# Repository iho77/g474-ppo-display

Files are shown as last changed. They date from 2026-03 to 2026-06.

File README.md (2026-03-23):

Shield: [][cc-by-nc]

This work is licensed under a
[Creative Commons Attribution-NonCommercial 4.0 International License][cc-by-nc].

[][cc-by-nc]

[cc-by-nc]: https://creativecommons.org/licenses/by-nc/4.0/
[cc-by-nc-image]: https://licensebuttons.net/l/by-nc/4.0/88x31.png
[cc-by-nc-shield]: https://img.shields.io/badge/License-CC%20BY--NC%204.0-lightgrey.svg

---

## DISCLAIMER — IMPORTANT, READ BEFORE USE

**THIS DEVICE IS A HOBBYIST PROTOTYPE AND EXPERIMENTAL RESEARCH TOOL. IT IS NOT A CERTIFIED DIVING INSTRUMENT, MEDICAL DEVICE, OR SAFETY EQUIPMENT OF ANY KIND.**

This firmware and associated hardware design are provided strictly for educational, experimental, and non-commercial purposes. The device has not been tested, validated, or certified to any safety standard (including but not limited to EN 13949, CE, FCC, or any diving equipment directive). Sensor readings, alarm thresholds, and all computed values may be inaccurate, delayed, or absent without warning.

**DO NOT use this device as a primary or backup oxygen monitoring system in any diving, life support, hyperbaric, medical, or other safety-critical application.** Reliance on this device in any situation involving risk to life or health is done entirely at the user's own risk.

TO THE MAXIMUM EXTENT PERMITTED BY APPLICABLE LAW, THE AUTHORS AND CONTRIBUTORS DISCLAIM ALL WARRANTIES, EXPRESS OR IMPLIED, INCLUDING BUT NOT LIMITED TO WARRANTIES OF MERCHANTABILITY, FITNESS FOR A PARTICULAR PURPOSE, AND NON-INFRINGEMENT. IN NO EVENT SHALL THE AUTHORS BE LIABLE FOR ANY DIRECT, INDIRECT, INCIDENTAL, SPECIAL, EXEMPLARY, OR CONSEQUENTIAL DAMAGES (INCLUDING DEATH, PERSONAL INJURY, OR PROPERTY DAMAGE) ARISING FROM THE USE OF OR INABILITY TO USE THIS DEVICE OR FIRMWARE, EVEN IF ADVISED OF THE POSSIBILITY OF SUCH DAMAGE.

**Use of this project implies full acceptance of these terms.**

---

# STM32G474 PPO Display Firmware

Firmware for a DIY PPO2 (Partial Pressure of Oxygen) display unit based on the **STM32G474CC** microcontroller. Designed for rebreather divers who want to build and understand their own monitoring electronics.

## Features

### PPO2 Monitoring
- Reads up to three galvanic oxygen cells simultaneously via dedicated ADC channels with OPAMPs
- Displays PPO2 in bar (e.g., 1.30) for each sensor on a colour TFT screen
- Two configurable setpoints (SP1 / SP2) with quick in-dive switching via button

### Warning System
- **DRIFT** (yellow): sensor has deviated more than the configured threshold from the active setpoint
- **NEAR LIMIT** (red border): PPO2 is approaching the configured minimum or maximum safe limit
- **CRITICAL** (red background): PPO2 has crossed the minimum or maximum limit — immediate action required
- Warnings are shown per-sensor with colour-coded borders, panel backgrounds, and text
- Haptic alerts via vibration motor with distinct patterns per severity:
  - Drift → one short pulse per second
  - Near limit → two medium pulses per second
  - Critical → three rapid pulses per second
- Press the menu button to silence the vibration while the visual warning remains on screen; the vibration will resume only if the warning level changes

### Sensor Drift Tracking
- Continuously monitors the rate of change of each sensor's PPO2 over a 3-minute window
- Drift rate (mbar/min) is displayed in real time to catch failing or degrading cells early

### Depth and Temperature
- Pressure sensor (MS5837) measures ambient pressure for depth calculation
- Depth displayed in metres; temperature available in raw sensor data screen

### Two-Point Sensor Calibration
- Calibrate any sensor against two known PPO2 reference points
- Calibration coefficients stored persistently in external SPI flash
- Sensor diagnostic screen shows sensitivity history to identify cell degradation over time

### Settings
- Configurable thresholds: minimum PPO, maximum PPO, warning distance, sensor divergence limit
- Two independent setpoints with configurable values
- Display brightness control with gamma correction
- All settings survive power cycles via wear-levelled external flash storage

### Dive Log
- Session data viewable on device

### Power Management
- Battery voltage and percentage displayed at all times
- Low battery warning
- Auto power-off after configurable idle period

---

## Hardware

- MCU: STM32G474CCTx (Cortex-M4, 170 MHz, 256 KB Flash, 128 KB RAM)
- Display: SPI TFT driven via DMA
- Pressure sensor: MS5837 via I2C
- External SPI flash for calibration/log storage (W25Q128)
- Vibration motor on PA0 (TIM5 CH1 PWM)
- Custom PCB (schematics in `Schematics/`)
- Enclosure model in `Housing/`

---

## Software Architecture

```
┌─────────────────────────────────────────────────────────────┐
│                        Application                          │
│                                                             │
│  screen_manager ──► screen_main / screen_settings /        │
│                      screen_calibration / screen_menu / … │
│       │                         │                           │
│  button (EXTI)            warning ◄──── sensor              │
│                             │               │               │
│                          vibro FSM      drift_tracker       │
│                         (TIM5 PWM)    (linear regression)   │
│                                           │                 │
│  settings_storage ◄──► ext_flash_storage  │                 │
│  (wear-levelled W25Q128 via SPI DMA)      │                 │
│                                           │                 │
│  pressure_sensor ◄──── ms5837 (I2C IT)   │                 │
│                                           │                 │
│  sensor_diagnostics ◄─────────────────────┘                 │
└─────────────────────────────────────────────────────────────┘
┌─────────────────────────────────────────────────────────────┐
│                    HAL / CubeMX Layer                       │
│  TIM6 1kHz scheduler │ ADC1-4 DMA │ SPI1/2 DMA │ I2C1 IT  │
│  TIM2 backlight PWM  │ TIM5 vibro │ EXTI buttons           │
└─────────────────────────────────────────────────────────────┘
```

### Major Modules

| Module | File(s) | Responsibility |
|---|---|---|
| Screen manager | `screen_manager.c/.h` | Screen lifecycle (create → load → delete), button routing |
| Warning | `warning.c/.h` | PPO2 threshold checks, visual styles, vibro state machine |
| Sensor | `sensor.c/.h` | ADC → microvolts → PPO2 conversion, validity tracking |
| Drift tracker | `drift_tracker.c/.h` | 3-minute linear regression on PPO2 samples (10 s interval) |
| Sensor diagnostics | `sensor_diagnostics.c/.h` | Calibration history analysis, sensitivity degradation detection |
| Pressure sensor | `pressure_sensor.c/.h` + `ms5837.c/.h` | Depth/temperature from MS5837 via I2C interrupt-driven FSM |
| Settings storage | `settings_storage.c/.h` | Read/write 7 user parameters to external flash |
| External flash | `ext_flash_storage.c/.h` + `w25q128.c/.h` | Wear-levelled page storage on W25Q128 SPI NOR flash |
| Button | `button.c/.h` | EXTI debounce, event queue for BTN_M / BTN_S |
| Display driver | `st7789v.c/.h` | SPI DMA flush, LVGL integration |

### Scheduler

A 1 kHz hardware timer (TIM6) drives four software tick rates:

| Rate | Handler | Work done |
|---|---|---|
| 5 ms | `g_flag_5ms` | LVGL render, vibro motor FSM tick |
| 20 ms | `g_flag_20ms` | Button event dispatch |
| 1 Hz | `g_flag_1hz` | Screen update, PPO2 warnings, battery check |
| 10 s | `g_flag_10s` | Drift tracker sample (3 sensors) |

---

## Repository Layout

```
Core/                          # CubeMX-generated core (Inc/, Src/)
STM32CubeIDE/
  Application/User/Core/       # Application source code
  Drivers/
    lvgl/                      # LVGL v8.3.11 (git submodule)
    lv_conf.h                  # LVGL configuration
  STM32G474CCTX_FLASH.ld       # Linker script (256 KB single-bank)
Drivers/                       # ST HAL / CMSIS (excluded from repo)
Schematics/                    # EasyEDA schematic exports
Housing/                       # FreeCAD enclosure model
stm32g474_PPO_Display.ioc      # STM32CubeMX project
```

> `Drivers/` (CMSIS + STM32G4xx HAL) is excluded — regenerate via STM32CubeMX.

---

## Safety Audit

A static safety audit of all application firmware was conducted on 2026-03-23, covering fault handling, ISR/main-loop data races, arithmetic overflow, sensor validity propagation, and stack usage.

- 15 findings identified (4 HIGH, 7 MEDIUM, 5 LOW / CRITICAL: 0)
- All actionable findings resolved in the same session
- Full report, per-finding evidence, and resolution details: [`.pipeline/safety_audit.md`](.pipeline/safety_audit.md)

---

## Building

Requires **STM32CubeIDE 1.19+**.

1. Clone with submodules:
   ```bash
   git clone --recurse-submodules https://github.com/iho77/g474-ppo-display.git
   ```
2. Open the workspace in STM32CubeIDE (`STM32CubeIDE/` folder).
3. Run **Project → Build All** (first build regenerates `subdir.mk` and `objects.list`).
4. After the first IDE build, command-line builds also work:
   ```bash
   cd STM32CubeIDE/Debug
   make -j4 all
   arm-none-eabi-size stm32g474_PPO_Display.elf
   ```

### Restoring excluded drivers

If you cloned fresh and `Drivers/` is empty, open the `.ioc` in STM32CubeMX and click **Generate Code** to restore CMSIS and HAL sources.

## Flash Memory Note

The G474CC ships with **DBANK=1** (dual 128 KB banks). The linker script uses a single 256 KB bank layout — ensure Option Bytes are set to `DBANK=0` before flashing.

---

## License

Application code: MIT.
LVGL: MIT (see `STM32CubeIDE/Drivers/lvgl/LICENCE.txt`).
ST HAL / CMSIS: BSD-3 / Apache-2.0 (see respective `LICENSE.txt` files).

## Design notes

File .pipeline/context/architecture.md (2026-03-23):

# Firmware Architecture

## Execution Model
Bare-metal super-loop. TIM6 fires at 1 kHz and sets scheduler flags; the main loop
polls those flags and dispatches periodic work. No RTOS.

## System Clock
PLL from 16 MHz HSI -> 96 MHz system clock (PLLN=12, PLLM=1, PLLR=2).
APB1/APB2 undivided (96 MHz). Flash latency 3 cycles.

## Module Map

| Module | File(s) | Purpose | ISR? | DMA? | Shared state? | External input? |
|---|---|---|---|---|---|---|
| Init & super-loop | Core/Src/main.c | Peripheral init (CubeMX), flag dispatch, HAL callbacks | No | Yes (ADC1-4, SPI2) | Yes | No |
| Interrupt vectors | Core/Src/stm32g4xx_it.c | EXTI, DMA, ADC, I2C, SPI, TIM ISR stubs | Yes | No | Yes | Yes |
| HAL low-level init | Core/Src/stm32g4xx_hal_msp.c | GPIO, DMA, clock MSP hooks | No | No | No | No |
| sensor.c | Application/User/Core/ | ADC->PPO2: Hampel spike filter + dual-EMA, VREFINT ratio calibration, battery voltage | No | Consumes DMA bufs | Yes | Yes (ADC1-4 DMA) |
| pressure_sensor.c | Application/User/Core/ | Depth calculation from MS5837 raw ADC, salt/fresh water selection | No | No | Yes | Yes (I2C1 IT) |
| ms5837.c | Application/User/Core/ | MS5837-30BA I2C driver -- IT-driven FSM (RESET->PROM->D2->D1->READ) | Yes (I2C1 callbacks) | No | Yes | Yes (I2C1) |
| drift_tracker.c | Application/User/Core/ | 3-minute linear regression on PPO2 (10 s samples, circular buffer) | No | No | Yes | No |
| warning.c | Application/User/Core/ | Threshold checks (CRITICAL/NEAR_CRITICAL/DRIFT), vibro motor 3-level PWM FSM | No | No | Yes | No |
| calibration.c | Application/User/Core/ | Two-point sensor calibration workflow | No | No | Yes | No |
| sensor_diagnostics.c | Application/User/Core/ | Calibration history analysis, sensitivity degradation detection | No | No | Yes | No |
| settings_storage.c | Application/User/Core/ | 7-parameter settings: brightness, thresholds, setpoints. Delegates to ext_flash_storage | No | No | Yes | No |
| ext_flash_storage.c | Application/User/Core/ | W25Q128 wear-levelled settings (ping-pong) + append-only calibration log; CRC32 validation | No | No | No | No |
| w25q128.c | Application/User/Core/ | Low-level W25Q128 SPI1 driver (read/write/erase) | No | No | No | No |
| st7789v.c | Application/User/Core/ | ST7789V SPI2 DMA display driver, 20-line partial framebuffer flush | No | Yes (SPI2 DMA1 Ch1) | Yes | No |
| screen_manager.c | Application/User/Core/ | Screen lifecycle: create -> load -> delete; factory pattern | No | No | Yes | No |
| button.c | Application/User/Core/ | EXTI debounce (50 ms), press/hold detection, event queue | Yes (EXTI callback) | No | Yes | Yes (PA2, PA3) |
| screens/screen_main.c | Application/User/Core/screens/ | Primary dive display: 3x PPO2, depth, battery, drift, setpoint selector | No | No | Yes (reads sensor) | No |
| screens/screen_calibration.c | Application/User/Core/screens/ | Two-point calibration UI workflow | No | No | Yes | No |
| screens/screen_settings.c | Application/User/Core/screens/ | User preference editor | No | No | Yes | No |
| screens/screen_menu.c | Application/User/Core/screens/ | Menu navigation hub | No | No | No | No |
| screens/screen_sensor_data.c | Application/User/Core/screens/ | Raw readings, diagnostics view | No | No | Yes | No |
| screens/screen_dive_log.c | Application/User/Core/screens/ | Historical calibration/dive data viewer | No | No | No | No |
| screens/screen_startup.c | Application/User/Core/screens/ | Boot splash, sensor stabilization wait | No | No | No | No |
| screens/screen_power_off.c | Application/User/Core/screens/ | Shutdown confirmation sequence | No | No | No | No |

## Interrupt Handlers

| ISR | Source | Priority | Notes |
|-----|---|---|---|
| SysTick_Handler | 1 ms tick | (HAL default) | Increments LVGL tick; calls button_tick() |
| TIM6_DAC_IRQHandler | TIM6 1 kHz | -- | Sets scheduler flags: g_flag_1hz/5ms/20ms/10s |
| EXTI2_IRQHandler | PA2 (BTN_M) | -- | Routes to button_exti_callback() |
| EXTI3_IRQHandler | PA3 (BTN_S) | -- | Routes to button_exti_callback() |
| DMA1_Channel1_IRQHandler | SPI2 TX complete | 0,0 | HAL_SPI_TxCpltCallback() -> lv_disp_flush_ready() |
| DMA1_Channel4_IRQHandler | ADC1 (SENSOR1) | 0,0 | HAL_ADC_ConvCpltCallback() -> sets g_adc1_new |
| DMA1_Channel5_IRQHandler | ADC2 (SENSOR2) | 0,0 | sets g_adc2_new |
| DMA1_Channel6_IRQHandler | ADC3 (SENSOR3) | 0,0 | sets g_adc3_new |
| DMA1_Channel7_IRQHandler | ADC4 (VREFINT+BAT) | 0,0 | sets g_adc4_new |
| ADC1_2_IRQHandler | ADC1/ADC2 shared | -- | HAL managed |
| ADC3_IRQHandler | ADC3 | -- | HAL managed |
| ADC4_IRQHandler | ADC4 | -- | HAL managed |
| I2C1_EV_IRQHandler | I2C1 event | -- | MS5837 FSM TX/RX complete callbacks |
| I2C1_ER_IRQHandler | I2C1 error | -- | MS5837 FSM -> idle |
| SPI2_IRQHandler | SPI2 general | -- | HAL managed |
| NMI_Handler / HardFault_Handler | -- | -- | Infinite loop (debugger attachment) |

## DMA Channels

| DMA Channel | Peripheral | Buffer | Circular? |
|---|---|---|---|
| DMA1 Channel 1 | SPI2 TX (LCD ST7789V) | 20-line partial framebuffer | No (per-flush) |
| DMA1 Channel 4 | ADC1 (SENSOR1 via OPAMP1) | ADC1_VAL[1] uint16_t | Yes |
| DMA1 Channel 5 | ADC2 (SENSOR2 via OPAMP2) | ADC2_VAL[1] uint16_t | Yes |
| DMA1 Channel 6 | ADC3 (SENSOR3 via OPAMP3) | ADC3_VAL[1] uint16_t | Yes |
| DMA1 Channel 7 | ADC4 (VREFINT + BAT PB12) | ADC4_VAL[2] uint16_t | Yes |

## Communication Interfaces

| Interface | Peripheral | Connected To | Notes |
|---|---|---|---|
| SPI1 | W25Q128 ext flash | PA5=SCK, PB4=MISO, PB5=MOSI, PB6=CS | Blocking HAL calls |
| SPI2 | ST7789V LCD | PB13=SCK, PB15=MOSI, PA10=CS, PA11=DC, PA12=RST | DMA TX, non-blocking |
| I2C1 | MS5837-30BA | Standard-mode, IT-driven (no DMA) | FSM: RESET->PROM->D2->D1->READ |
| ADC1 | OPAMP1 output | SENSOR1 galvanic O2 cell | 16x oversampling, continuous+DMA |
| ADC2 | OPAMP2 output | SENSOR2 galvanic O2 cell | 16x oversampling, continuous+DMA |
| ADC3 | OPAMP3 output | SENSOR3 galvanic O2 cell | continuous+DMA |
| ADC4 ch1/ch3 | VREFINT + PB12 | Internal ref + battery divider | Scan 2ch, DMA |
| TIM5 CH1 | Vibro motor | PA0 (PWM) | 200 Hz, duty 50/75/99% per warning level |
| TIM2 CH3 | LCD backlight | PA9 (PWM) | Gamma-corrected brightness |
| TIM6 | Scheduler | (internal) | 1 kHz, master for periodic flags |
| GPIO EXTI2/3 | Buttons | PA2 (BTN_M), PA3 (BTN_S) | 50 ms debounce |

## GPIO Pin Reference

| Signal | Pin | Function |
|---|-----|---|
| VIB_PWM | PA0 | TIM5 CH1 -- vibro motor PWM |
| SENSOR_1 | PA1 | OPAMP1 input (analog) |
| BTN_M | PA2 | Button Main -- EXTI2 |
| BTN_S | PA3 | Button Select -- EXTI3 |
| FL_SCK | PA5 | SPI1 clock (W25Q128) |
| SENSOR_2 | PA7 | OPAMP2 input (analog) |
| TFT_BLK | PA9 | TIM2 CH3 -- LCD backlight PWM |
| TFT_CS | PA10 | LCD chip-select |
| TFT_DC | PA11 | LCD data/command |
| TFT_RST | PA12 | LCD reset |
| FL_MISO | PB4 | SPI1 MISO (W25Q128) |
| FL_MOSI | PB5 | SPI1 MOSI (W25Q128) |
| FL_CS | PB6 | SPI1 CS (W25Q128) |
| SENSOR_3 | PB0 | OPAMP3 input (analog) |
| SENS_BAT | PB12 | ADC4 ch3 -- battery voltage (3x divider) |
| TFT_SCK | PB13 | SPI2 clock (LCD) |
| TFT_MOSI | PB15 | SPI2 MOSI (LCD) |

## Scheduler Flags (TIM6 @ 1 kHz -> HAL_TIM_PeriodElapsedCallback)

| Flag | Period | Used for |
|---|---|---|
| g_flag_5ms | 5 ms | LVGL timer handler, vibro_tick_5ms() |
| g_flag_20ms | 20 ms | Button event dispatch |
| g_flag_1hz | 1 s | Screen update, PPO2 warning check, battery check |
| g_flag_10s | 10 s | Drift tracker sample |

## Shared Variables (ISR <-> main / module <-> module)

| Variable | Type | Writers | Readers | Protection |
|---|---|---|---|---|
| ADC1_VAL / ADC2_VAL / ADC3_VAL | volatile uint16_t[1] | DMA ISR | sensor.c | atomic flag g_adc1/2/3_new |
| ADC4_VAL | volatile uint16_t[2] | DMA ISR | sensor.c | atomic flag g_adc4_new |
| g_adc1_new .. g_adc4_new | volatile bool / atomic | HAL_ADC_ConvCpltCallback | sensor.c | volatile write, single-reader |
| button event queue | ring buffer | EXTI ISR (button.c) | main loop | volatile head/tail indices |
| sensor_data struct | struct | sensor.c | warning.c, screens | single-writer, read in main loop |
| alarm state | enum | warning.c | screens, vibro FSM | single-writer |
| screen handle | lv_obj_t* | screen_manager.c | screens | single-writer |
| settings struct | struct | settings_storage.c | multiple modules | loaded once at boot, written on save |
| MS5837 FSM state | enum | I2C callbacks (ms5837.c) | pressure_sensor.c | volatile, single-writer |

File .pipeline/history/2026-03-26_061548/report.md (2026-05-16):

# Static Analysis Report — PPO Display

**Run timestamp:** 2026-03-26_061548
**MCU:** STM32G431KB

## Summary

| Severity | Count |
|---|---|
| CRITICAL | 0 |
| HIGH | 12 |
| MEDIUM | 18 |
| LOW | 0 |
| **Total** | **30** |

## Findings by Tool

- **clang-tidy**: 12 findings
- **flawfinder**: 7 findings
- **lizard**: 11 findings

## Hotspot Files (most findings)

- **STM32CubeIDE/Application/User/Core/screens/screen_calibration.c**: 4 findings
- **STM32CubeIDE/Application/User/Core/dive_log.c**: 3 findings
- **STM32CubeIDE/Application/User/Core/sensor.c**: 3 findings
- **Core/Src/main.c**: 2 findings
- **STM32CubeIDE/Application/User/Core/ext_flash_storage.c**: 2 findings
- **STM32CubeIDE/Application/User/Core/screens/screen_dive_log.c**: 2 findings
- **STM32CubeIDE/Application/User/Core/screens/screen_main.c**: 2 findings
- **STM32CubeIDE/Application/User/Core/screens/screen_sensor_data.c**: 1 findings
- **STM32CubeIDE/Application/User/Core/screens/screen_settings.c**: 1 findings
- **STM32CubeIDE/Application/User/Core/sensor_diagnostics.c**: 1 findings

## Detailed Findings

### HIGH (12)

**HIGH-1** | `Core/Src/main.c:766` | `clang-tidy` | `bugprone-narrowing-conversions`
> narrowing conversion from 'int' to signed type 'int8_t' (aka 'signed char') is implementation-defined

**HIGH-2** | `STM32CubeIDE/Application/User/Core/dive_log.c:109` | `clang-tidy` | `clang-analyzer-security.insecureAPI.DeprecatedOrUnsafeBufferHandling`
> Call to function 'memset' is insecure as it does not provide security checks introduced in the C11 standard. Replace with analogous functions that support length arguments or provides boundary checks such as 'memset_s' in case of C11

**HIGH-3** | `STM32CubeIDE/Application/User/Core/ext_flash_storage.c:146` | `clang-tidy` | `clang-analyzer-security.insecureAPI.DeprecatedOrUnsafeBufferHandling`
> Call to function 'memset' is insecure as it does not provide security checks introduced in the C11 standard. Replace with analogous functions that support length arguments or provides boundary checks such as 'memset_s' in case of C11

**HIGH-4** | `STM32CubeIDE/Application/User/Core/screens/screen_calibration.c:518` | `clang-tidy` | `clang-analyzer-security.insecureAPI.DeprecatedOrUnsafeBufferHandling`
> Call to function 'snprintf' is insecure as it does not provide security checks introduced in the C11 standard. Replace with analogous functions that support length arguments or provides boundary checks such as 'snprintf_s' in case of C11

**HIGH-5** | `STM32CubeIDE/Application/User/Core/screens/screen_dive_log.c:133` | `clang-tidy` | `clang-analyzer-security.insecureAPI.DeprecatedOrUnsafeBufferHandling`
> Call to function 'snprintf' is insecure as it does not provide security checks introduced in the C11 standard. Replace with analogous functions that support length arguments or provides boundary checks such as 'snprintf_s' in case of C11

**HIGH-6** | `STM32CubeIDE/Application/User/Core/screens/screen_dive_log.c:265` | `clang-tidy` | `bugprone-narrowing-conversions`
> narrowing conversion from 'int' to signed type 'lv_coord_t' (aka 'short') is implementation-defined

**HIGH-7** | `STM32CubeIDE/Application/User/Core/screens/screen_sensor_data.c:114` | `clang-tidy` | `clang-analyzer-security.insecureAPI.DeprecatedOrUnsafeBufferHandling`
> Call to function 'snprintf' is insecure as it does not provide security checks introduced in the C11 standard. Replace with analogous functions that support length arguments or provides boundary checks such as 'snprintf_s' in case of C11

**HIGH-8** | `STM32CubeIDE/Application/User/Core/screens/screen_settings.c:95` | `clang-tidy` | `clang-analyzer-security.insecureAPI.DeprecatedOrUnsafeBufferHandling`
> Call to function 'snprintf' is insecure as it does not provide security checks introduced in the C11 standard. Replace with analogous functions that support length arguments or provides boundary checks such as 'snprintf_s' in case of C11

**HIGH-9** | `STM32CubeIDE/Application/User/Core/sensor.c:205` | `clang-tidy` | `bugprone-implicit-widening-of-multiplication-result`
> performing an implicit widening conversion to type 'unsigned long' of a multiplication performed in type 'int'

**HIGH-10** | `STM32CubeIDE/Application/User/Core/sensor.c:206` | `clang-tidy` | `bugprone-narrowing-conversions`
> narrowing conversion from 'unsigned int' to signed type 'int32_t' (aka 'int') is implementation-defined

**HIGH-11** | `STM32CubeIDE/Application/User/Core/sensor_diagnostics.c:192` | `clang-tidy` | `clang-analyzer-security.insecureAPI.DeprecatedOrUnsafeBufferHandling`
> Call to function 'memset' is insecure as it does not provide security checks introduced in the C11 standard. Replace with analogous functions that support length arguments or provides boundary checks such as 'memset_s' in case of C11

**HIGH-12** | `STM32CubeIDE/Application/User/Core/w25q128.c:216` | `clang-tidy` | `clang-analyzer-security.insecureAPI.DeprecatedOrUnsafeBufferHandling`
> Call to function 'memset' is insecure as it does not provide security checks introduced in the C11 standard. Replace with analogous functions that support length arguments or provides boundary checks such as 'memset_s' in case of C11

### MEDIUM (18)

**MEDIUM-1** | `STM32CubeIDE/Application/User/Core/dive_log.c:133:5` | `flawfinder` | `buffer`
> memcpy:Does not check for buffer overflows when copying to destination (CWE-120).  Make sure destination can always hold the source data.
> *Risk level: 2/5*

**MEDIUM-2** | `STM32CubeIDE/Application/User/Core/screens/screen_dive_log.c:125:12` | `flawfinder` | `buffer`
> char:Statically-sized arrays can be improperly restricted, leading to potential overflows or other issues (CWE-119!/CWE-120).  Perform bounds checking, use functions that limit length, or ensure that the size is larger than the maximum possible length.
> *Risk level: 2/5*

**MEDIUM-3** | `STM32CubeIDE/Application/User/Core/screens/screen_dive_log.c:158:12` | `flawfinder` | `buffer`
> char:Statically-sized arrays can be improperly restricted, leading to potential overflows or other issues (CWE-119!/CWE-120).  Perform bounds checking, use functions that limit length, or ensure that the size is larger than the maximum possible length.
> *Risk level: 2/5*

**MEDIUM-4** | `STM32CubeIDE/Application/User/Core/screens/screen_dive_log.c:159:12` | `flawfinder` | `buffer`
> char:Statically-sized arrays can be improperly restricted, leading to potential overflows or other issues (CWE-119!/CWE-120).  Perform bounds checking, use functions that limit length, or ensure that the size is larger than the maximum possible length.
> *Risk level: 2/5*

**MEDIUM-5** | `STM32CubeIDE/Application/User/Core/screens/screen_main.c:761:9` | `flawfinder` | `buffer`
> char:Statically-sized arrays can be improperly restricted, leading to potential overflows or other issues (CWE-119!/CWE-120).  Perform bounds checking, use functions that limit length, or ensure that the size is larger than the maximum possible length.
> *Risk level: 2/5*

**MEDIUM-6** | `STM32CubeIDE/Application/User/Core/screens/screen_main.c:780:9` | `flawfinder` | `buffer`
> char:Statically-sized arrays can be improperly restricted, leading to potential overflows or other issues (CWE-119!/CWE-120).  Perform bounds checking, use functions that limit length, or ensure that the size is larger than the maximum possible length.
> *Risk level: 2/5*

**MEDIUM-7** | `STM32CubeIDE/Application/User/Core/screens/screen_sensor_data.c:111:12` | `flawfinder` | `buffer`
> char:Statically-sized arrays can be improperly restricted, leading to potential overflows or other issues (CWE-119!/CWE-120).  Perform bounds checking, use functions that limit length, or ensure that the size is larger than the maximum possible length.
> *Risk level: 2/5*

**MEDIUM-8** | `Core/Src/main.c:517` | `lizard` | `complexity(warning: main)`
> Cyclomatic complexity 27 exceeds threshold 15
> *Function: warning: main*

**MEDIUM-9** | `STM32CubeIDE/Application/User/Core/screens/screen_calibration.c:56` | `lizard` | `complexity(warning: build_screen_content)`
> Function length 228 lines exceeds threshold 75
> *Function: warning: build_screen_content*

**MEDIUM-10** | `STM32CubeIDE/Application/User/Core/screens/screen_calibration.c:513` | `lizard` | `complexity(warning: screen_calibration_update)`
> Cyclomatic complexity 22 exceeds threshold 15
> *Function: warning: screen_calibration_update*

**MEDIUM-11** | `STM32CubeIDE/Application/User/Core/screens/screen_calibration.c:634` | `lizard` | `complexity(warning: screen_calibration_on_button)`
> Cyclomatic complexity 21 exceeds threshold 15
> *Function: warning: screen_calibration_on_button*

**MEDIUM-12** | `STM32CubeIDE/Application/User/Core/screens/screen_main.c:87` | `lizard` | `complexity(warning: build_screen_content)`
> Function length 309 lines exceeds threshold 75
> *Function: warning: build_screen_content*

**MEDIUM-13** | `STM32CubeIDE/Application/User/Core/screens/screen_main.c:519` | `lizard` | `complexity(warning: screen_main_update)`
> Cyclomatic complexity 46 exceeds threshold 15
> *Function: warning: screen_main_update*

**MEDIUM-14** | `STM32CubeIDE/Application/User/Core/dive_log.c:291` | `lizard` | `complexity(warning: dive_log_tick_1hz)`
> Cyclomatic complexity 36 exceeds threshold 15
> *Function: warning: dive_log_tick_1hz*

**MEDIUM-15** | `STM32CubeIDE/Application/User/Core/dive_log.c:401` | `lizard` | `complexity(warning: dive_log_iterate)`
> Cyclomatic complexity 19 exceeds threshold 15
> *Function: warning: dive_log_iterate*

**MEDIUM-16** | `STM32CubeIDE/Application/User/Core/ext_flash_storage.c:535` | `lizard` | `complexity(warning: ext_cal_iterate)`
> Cyclomatic complexity 16 exceeds threshold 15
> *Function: warning: ext_cal_iterate*

**MEDIUM-17** | `STM32CubeIDE/Application/User/Core/screen_manager.c:94` | `lizard` | `complexity(warning: screen_manager_handle_button)`
> Cyclomatic complexity 17 exceeds threshold 15
> *Function: warning: screen_manager_handle_button*

**MEDIUM-18** | `STM32CubeIDE/Application/User/Core/sensor.c:182` | `lizard` | `complexity(warning: sensor_data_update)`
> Cyclomatic complexity 23 exceeds threshold 15
> *Function: warning: sensor_data_update*

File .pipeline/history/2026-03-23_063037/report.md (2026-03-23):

# Static Analysis Report — PPO Display

**Run timestamp:** 2026-03-23_063037
**MCU:** STM32G431KB

## Summary

| Severity | Count |
|---|---|
| CRITICAL | 0 |
| HIGH | 1 |
| MEDIUM | 9 |
| LOW | 0 |
| **Total** | **10** |

## Findings by Tool

- **cppcheck**: 1 findings
- **flawfinder**: 1 findings
- **lizard**: 8 findings

## Hotspot Files (most findings)

- **STM32CubeIDE/Application/User/Core/screens/screen_calibration.c**: 3 findings
- **STM32CubeIDE/Application/User/Core/sensor.c**: 2 findings
- **STM32CubeIDE/Application/User/Core/screens/screen_main.c**: 2 findings
- **STM32CubeIDE/Application/User/Core/screens/screen_sensor_data.c:111**: 1 findings
- **Core/Src/main.c**: 1 findings
- **STM32CubeIDE/Application/User/Core/ext_flash_storage.c**: 1 findings

## Detailed Findings

### HIGH (1)

**HIGH-1** | `STM32CubeIDE/Application/User/Core/sensor.c:104` | `cppcheck` | `uninitvar`
> Uninitialized variable: d

### MEDIUM (9)

**MEDIUM-1** | `STM32CubeIDE/Application/User/Core/screens/screen_sensor_data.c:111:12` | `flawfinder` | `buffer`
> char:Statically-sized arrays can be improperly restricted, leading to potential overflows or other issues (CWE-119!/CWE-120).  Perform bounds checking, use functions that limit length, or ensure that the size is larger than the maximum possible length.
> *Risk level: 2/5*

**MEDIUM-2** | `Core/Src/main.c:550` | `lizard` | `complexity(warning: main)`
> Cyclomatic complexity 23 exceeds threshold 15
> *Function: warning: main*

**MEDIUM-3** | `STM32CubeIDE/Application/User/Core/screens/screen_calibration.c:56` | `lizard` | `complexity(warning: build_screen_content)`
> Function length 228 lines exceeds threshold 75
> *Function: warning: build_screen_content*

**MEDIUM-4** | `STM32CubeIDE/Application/User/Core/screens/screen_calibration.c:513` | `lizard` | `complexity(warning: screen_calibration_update)`
> Cyclomatic complexity 22 exceeds threshold 15
> *Function: warning: screen_calibration_update*

**MEDIUM-5** | `STM32CubeIDE/Application/User/Core/screens/screen_calibration.c:634` | `lizard` | `complexity(warning: screen_calibration_on_button)`
> Cyclomatic complexity 21 exceeds threshold 15
> *Function: warning: screen_calibration_on_button*

**MEDIUM-6** | `STM32CubeIDE/Application/User/Core/screens/screen_main.c:87` | `lizard` | `complexity(warning: build_screen_content)`
> Function length 309 lines exceeds threshold 75
> *Function: warning: build_screen_content*

**MEDIUM-7** | `STM32CubeIDE/Application/User/Core/screens/screen_main.c:519` | `lizard` | `complexity(warning: screen_main_update)`
> Cyclomatic complexity 46 exceeds threshold 15
> *Function: warning: screen_main_update*

**MEDIUM-8** | `STM32CubeIDE/Application/User/Core/ext_flash_storage.c:535` | `lizard` | `complexity(warning: ext_cal_iterate)`
> Cyclomatic complexity 16 exceeds threshold 15
> *Function: warning: ext_cal_iterate*

**MEDIUM-9** | `STM32CubeIDE/Application/User/Core/sensor.c:182` | `lizard` | `complexity(warning: sensor_data_update)`
> Cyclomatic complexity 23 exceeds threshold 15
> *Function: warning: sensor_data_update*

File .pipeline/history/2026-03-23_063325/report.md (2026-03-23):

# Static Analysis Report — PPO Display

**Run timestamp:** 2026-03-23_063325
**MCU:** STM32G431KB

## Summary

| Severity | Count |
|---|---|
| CRITICAL | 0 |
| HIGH | 8 |
| MEDIUM | 9 |
| LOW | 0 |
| **Total** | **17** |

## Findings by Tool

- **clang-tidy**: 8 findings
- **flawfinder**: 1 findings
- **lizard**: 8 findings

## Hotspot Files (most findings)

- **STM32CubeIDE/Application/User/Core/screens/screen_calibration.c**: 4 findings
- **STM32CubeIDE/Application/User/Core/sensor.c**: 3 findings
- **STM32CubeIDE/Application/User/Core/ext_flash_storage.c**: 2 findings
- **STM32CubeIDE/Application/User/Core/screens/screen_main.c**: 2 findings
- **STM32CubeIDE/Application/User/Core/screens/screen_sensor_data.c**: 1 findings
- **STM32CubeIDE/Application/User/Core/screens/screen_settings.c**: 1 findings
- **STM32CubeIDE/Application/User/Core/sensor_diagnostics.c**: 1 findings
- **STM32CubeIDE/Application/User/Core/w25q128.c**: 1 findings
- **STM32CubeIDE/Application/User/Core/screens/screen_sensor_data.c:111**: 1 findings
- **Core/Src/main.c**: 1 findings

## Detailed Findings

### HIGH (8)

**HIGH-1** | `STM32CubeIDE/Application/User/Core/ext_flash_storage.c:146` | `clang-tidy` | `clang-analyzer-security.insecureAPI.DeprecatedOrUnsafeBufferHandling`
> Call to function 'memset' is insecure as it does not provide security checks introduced in the C11 standard. Replace with analogous functions that support length arguments or provides boundary checks such as 'memset_s' in case of C11

**HIGH-2** | `STM32CubeIDE/Application/User/Core/screens/screen_calibration.c:518` | `clang-tidy` | `clang-analyzer-security.insecureAPI.DeprecatedOrUnsafeBufferHandling`
> Call to function 'snprintf' is insecure as it does not provide security checks introduced in the C11 standard. Replace with analogous functions that support length arguments or provides boundary checks such as 'snprintf_s' in case of C11

**HIGH-3** | `STM32CubeIDE/Application/User/Core/screens/screen_sensor_data.c:114` | `clang-tidy` | `clang-analyzer-security.insecureAPI.DeprecatedOrUnsafeBufferHandling`
> Call to function 'snprintf' is insecure as it does not provide security checks introduced in the C11 standard. Replace with analogous functions that support length arguments or provides boundary checks such as 'snprintf_s' in case of C11

**HIGH-4** | `STM32CubeIDE/Application/User/Core/screens/screen_settings.c:95` | `clang-tidy` | `clang-analyzer-security.insecureAPI.DeprecatedOrUnsafeBufferHandling`
> Call to function 'snprintf' is insecure as it does not provide security checks introduced in the C11 standard. Replace with analogous functions that support length arguments or provides boundary checks such as 'snprintf_s' in case of C11

**HIGH-5** | `STM32CubeIDE/Application/User/Core/sensor.c:205` | `clang-tidy` | `bugprone-implicit-widening-of-multiplication-result`
> performing an implicit widening conversion to type 'unsigned long' of a multiplication performed in type 'int'

**HIGH-6** | `STM32CubeIDE/Application/User/Core/sensor.c:206` | `clang-tidy` | `bugprone-narrowing-conversions`
> narrowing conversion from 'unsigned int' to signed type 'int32_t' (aka 'int') is implementation-defined

**HIGH-7** | `STM32CubeIDE/Application/User/Core/sensor_diagnostics.c:192` | `clang-tidy` | `clang-analyzer-security.insecureAPI.DeprecatedOrUnsafeBufferHandling`
> Call to function 'memset' is insecure as it does not provide security checks introduced in the C11 standard. Replace with analogous functions that support length arguments or provides boundary checks such as 'memset_s' in case of C11

**HIGH-8** | `STM32CubeIDE/Application/User/Core/w25q128.c:216` | `clang-tidy` | `clang-analyzer-security.insecureAPI.DeprecatedOrUnsafeBufferHandling`
> Call to function 'memset' is insecure as it does not provide security checks introduced in the C11 standard. Replace with analogous functions that support length arguments or provides boundary checks such as 'memset_s' in case of C11

### MEDIUM (9)

**MEDIUM-1** | `STM32CubeIDE/Application/User/Core/screens/screen_sensor_data.c:111:12` | `flawfinder` | `buffer`
> char:Statically-sized arrays can be improperly restricted, leading to potential overflows or other issues (CWE-119!/CWE-120).  Perform bounds checking, use functions that limit length, or ensure that the size is larger than the maximum possible length.
> *Risk level: 2/5*

**MEDIUM-2** | `Core/Src/main.c:550` | `lizard` | `complexity(warning: main)`
> Cyclomatic complexity 23 exceeds threshold 15
> *Function: warning: main*

**MEDIUM-3** | `STM32CubeIDE/Application/User/Core/screens/screen_calibration.c:56` | `lizard` | `complexity(warning: build_screen_content)`
> Function length 228 lines exceeds threshold 75
> *Function: warning: build_screen_content*

**MEDIUM-4** | `STM32CubeIDE/Application/User/Core/screens/screen_calibration.c:513` | `lizard` | `complexity(warning: screen_calibration_update)`
> Cyclomatic complexity 22 exceeds threshold 15
> *Function: warning: screen_calibration_update*

**MEDIUM-5** | `STM32CubeIDE/Application/User/Core/screens/screen_calibration.c:634` | `lizard` | `complexity(warning: screen_calibration_on_button)`
> Cyclomatic complexity 21 exceeds threshold 15
> *Function: warning: screen_calibration_on_button*

**MEDIUM-6** | `STM32CubeIDE/Application/User/Core/screens/screen_main.c:87` | `lizard` | `complexity(warning: build_screen_content)`
> Function length 309 lines exceeds threshold 75
> *Function: warning: build_screen_content*

**MEDIUM-7** | `STM32CubeIDE/Application/User/Core/screens/screen_main.c:519` | `lizard` | `complexity(warning: screen_main_update)`
> Cyclomatic complexity 46 exceeds threshold 15
> *Function: warning: screen_main_update*

**MEDIUM-8** | `STM32CubeIDE/Application/User/Core/ext_flash_storage.c:535` | `lizard` | `complexity(warning: ext_cal_iterate)`
> Cyclomatic complexity 16 exceeds threshold 15
> *Function: warning: ext_cal_iterate*

**MEDIUM-9** | `STM32CubeIDE/Application/User/Core/sensor.c:182` | `lizard` | `complexity(warning: sensor_data_update)`
> Cyclomatic complexity 23 exceeds threshold 15
> *Function: warning: sensor_data_update*

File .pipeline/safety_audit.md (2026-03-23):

# STM32G474 Firmware — Safety Audit Report

**Audit date:** 2026-03-23
**Compiler context:** GCC ARM, bare-metal, no RTOS.
**Scope:** All custom application files in `STM32CubeIDE/Application/User/Core/`, `Core/Src/main.c`, `Core/Src/stm32g4xx_it.c`.

---

## Executive Summary

| Severity | Count |
|---|---|
| CRITICAL | 0 |
| HIGH | 4 |
| MEDIUM | 7 |
| LOW | 5 |

**Top 3 highest-risk areas:**
1. **No watchdog** — a main-loop stall (LVGL, DMA, I2C hang) leaves a diving device permanently unresponsive with no alarms, no display, and no depth monitoring.
2. **Fault handlers are `while(1)` loops** — HardFault/BusFault during a dive silently freezes all outputs including the PPO2 warning system.
3. **`ms5837_i2c_bus_recover1()` calls `HAL_I2C_Init()`** — explicit policy violation (CLAUDE.md rule 5) that risks corrupting I2C DMA state.

**Overall assessment: NEEDS REMEDIATION** — no findings that cause guaranteed runtime failure under normal conditions, but findings #1 (no watchdog) and #2 (fault handlers) represent unacceptable safety gaps for a mission-critical diving instrument.

---

## Detailed Findings Table

| # | File:Line | Severity | Category | Finding | Evidence | Remediation |
|---|---|---|---|---|---|---|
| 1 | `main.c` (no watchdog) | HIGH | D4 | No IWDG configured or fed anywhere. A main-loop stall (LVGL deadlock, DMA hung) leaves the device frozen indefinitely. During a dive, PPO2 alarms and depth display silently stop updating. | Grepped entire codebase — `IWDG` not referenced. | Configure IWDG at ~4-8 s. Feed it in the main loop 1Hz block or 5ms block. Ensure the feed only happens when the main loop is executing (not unconditionally in an ISR). |
| 2 | `stm32g4xx_it.c:96-151` | HIGH | D8 | All fault handlers (`HardFault_Handler`, `BusFault_Handler`, `MemManage_Handler`, `UsageFault_Handler`, `NMI_Handler`) are `while(1)` infinite loops. A HardFault during a dive silently freezes the display and all alarms. | `void HardFault_Handler(void) { while (1) { } }` | Add a brief delay (allow DMA to drain), then call `vibro_hw_stop()` or drive GPIO warning line high, then `NVIC_SystemReset()`. Capture fault diagnostics in a `__no_init` RAM structure for post-mortem. |
| 3 | `main.c:543-556` | HIGH | E5 | `ms5837_i2c_bus_recover1()` calls `HAL_I2C_Init(&hi2c1)` directly. This re-initializes the I2C peripheral, potentially corrupting ongoing IT transfers and the HAL internal state machine. Violates CLAUDE.md rule 5. | `if (HAL_I2C_Init(&hi2c1) != HAL_OK) { // Handle Init Error }` | This function is not called anywhere in the visible codebase — confirm it is dead code, then remove it. If bus recovery is needed, reset the peripheral using the RCC reset sequence and wait for HAL to return to READY state, without calling HAL_I2C_Init during normal operation. |
| 4 | `main.c:656-658` | MEDIUM | D8 | If `ms5837_init()` fails at boot, `ms5837_initialized` stays false and the FSM never runs. However, `pressure_sensor_init()` already set `pressure.pressure_valid = true` and `pressure.pressure_mbar = ATMOSPHERIC_PRESSURE_MBAR`. The display and depth timer will trust stale/default pressure data without knowing the sensor failed. | `if (ms5837_init(...) == MS5837_OK) { ms5837_initialized = true; }` (no else branch) | In the else branch: `sensor_data.pressure.pressure_valid = false;`. Also log the failure for diagnostic purposes. The depth timer already guards on `pressure_valid`, so setting it false prevents a phantom dive timer. |
| 5 | `pressure_sensor.c:106` | MEDIUM | B1 | At depths near the sensor's 30-bar limit the intermediate product `delta_pressure_mbar * DEPTH_COEFFICIENT_NUMERATOR` overflows `int32_t`. `delta_pressure_mbar` is `surface_pressure_mbar - current`, with `current` scaled ×100. At 30 bar: `current = 3,000,000`, delta ≈ `−2,900,000`, product ≈ `−2,885,000,000` which exceeds `INT32_MIN (−2,147,483,648)`. | `int32_t depth_mm = (delta_pressure_mbar * DEPTH_COEFFICIENT_NUMERATOR) / DEPTH_COEFFICIENT_DENOMINATOR;` | Use `int64_t` for the intermediate: `int32_t depth_mm = (int32_t)(((int64_t)delta_pressure_mbar * 995) / 10000);` |
| 6 | `button.c:71-75` | MEDIUM | C5 | `button_get_event()` reads then clears `pending_event` in two non-atomic operations. An EXTI ISR that fires between the read and the clear overwrites the value with a new event, which is then cleared invisibly. | `btn_event_t evt = pending_event; pending_event = BTN_NONE;` | Use `__disable_irq()` / `__enable_irq()` around the read-clear pair: `__disable_irq(); evt = pending_event; pending_event = BTN_NONE; __enable_irq();` |
| 7 | `main.c:773-777` | MEDIUM | C7 | `ADC4_VAL[2]` holds two 16-bit values (VREFINT, BAT) written by DMA in circular mode. DMA writes continuously. Main loop reads `ADC4_VAL[0]` then `ADC4_VAL[1]` as two separate accesses. A DMA half-complete interrupt between these reads could result in a torn pair (VREFINT from one cycle, BAT from the next). | `sensor_data_update(REFERENCE, ADC4_VAL[0]); sensor_data_update(BAT, ADC4_VAL[1]);` | Copy both values atomically under `__disable_irq()` before calling `sensor_data_update`. |
| 8 | `calibration.c:27` | MEDIUM | A2 | `calibrate_sensor()` writes to `sensor_data.os_s_cal_state[SensorID]` without first validating `SensorID < (SENSOR_COUNT - 2)`. The array is size 3 (indices 0-2). If the caller passes SensorID ≥ 3, this is an out-of-bounds write into adjacent struct fields. | `sensor_data.os_s_cal_state[SensorID] = NON_CALIBRATED;` | Add `if (SensorID >= (SENSOR_COUNT - 2)) return;` at the top of `calibrate_sensor()`. |
| 9 | `ext_flash_storage.c:547` | MEDIUM | A3 | `ext_cal_iterate()` allocates `entry_ref_t valid[64]` on the stack — 64 × 8 bytes = 512 bytes. This is called from the main loop when the dive log screen loads. Combined with other local variables and call chain, this risks stack overflow if the stack is tight. | `entry_ref_t valid[EXT_CAL_ITER_MAX_SORT];` where `EXT_CAL_ITER_MAX_SORT = 64U` | Move to a static local: `static entry_ref_t valid[EXT_CAL_ITER_MAX_SORT];` — eliminates stack use at the cost of 512 bytes BSS. Verify with `arm-none-eabi-size` before and after. |
| 10 | `sensor.c:45` | LOW | F4 | `#define MAX_STABILITY_WAIT 0` — comment says "Timeout after warmup (~3s)" but value is zero, which disables the timeout entirely. Code depending on this for sensor validity timeout silently never fires. | `#define MAX_STABILITY_WAIT  0 // Timeout after warmup (~3s)` | Either restore the intended timeout value or rename to `MAX_STABILITY_WAIT_DISABLED` and add a comment marking it as intentionally disabled. Remove dead code at lines 268-273 if the timeout is never re-enabled. |
| 11 | `main.c:77` | LOW | F3 | Unused variable pollutes global namespace. | `uint32_t something = 10;` | Delete. |
| 12 | `sensor.h:120-125` | LOW | F4 | Duplicate include guard at end of file — a second `#ifndef SENSOR_H_ / #define SENSOR_H_ / #endif` block after the first guard closes at line 112. Harmless but indicates copy-paste error. | Lines 120-125 of `sensor.h` | Remove the duplicate guard block. |
| 13 | `main.c:108-110` | LOW | F3 | `vbias_effective_mv` and `vbias_counts_for_adc2` declared as globals, initialized, but not visibly used in the main loop or any callback. | `uint32_t vbias_effective_mv = 0; uint32_t vbias_counts_for_adc2 = 0;` | Verify these are unused; if so, remove. |
| 14 | `sensor.c:107-168` | LOW | F2 | `filter_step_sensor` has cyclomatic complexity ~12, approaching the recommended limit of 15. Hampel filter, EMA, baseline, and init paths are all interleaved. | Function spans 61 lines with nested conditionals. | No immediate action required. Consider extracting the Hampel filter block into a `static inline int32_t hampel_clip(...)` helper. |
| 15 | `ms5837.c:99` | LOW | D1 | No CRC verification of PROM data after `ms5837_read_prom()`. The `crc_prom` field is extracted but never validated against a computed CRC of the 7 PROM words. A corrupted PROM (EMI, flash retention fault) would silently produce wrong calibration and thus wrong depth readings. | `calib->crc_prom = (calib->C[0] >> 12) & 0x0F;` — CRC extracted but not verified | Implement the 4-bit CRC check per MS5837 datasheet §2.4 and return `MS5837_ERROR_CRC` if it fails. |

## Resolution Summary — 2026-03-23

All actionable findings addressed in a single remediation session. Build verified clean after all changes.

### Pre-existing (confirmed resolved before this session)

| # | Finding | Resolution |
|---|---|---|
| 1 | No IWDG configured | IWDG was already configured via `.ioc` and fed with `HAL_IWDG_Refresh(&hiwdg)` in the 1 Hz scheduler block (`main.c:761`). |
| 3 | `ms5837_i2c_bus_recover1()` calls `HAL_I2C_Init` | Function does not exist anywhere in the codebase. Finding not applicable. |

### Fixed in this session

| # | Severity | Finding | File | Fix applied |
|---|---|---|---|---|
| 2 | HIGH | Fault handlers loop forever | `Core/Src/stm32g4xx_it.c` | Added `TIM5->CCR1 = 0U; NVIC_SystemReset();` inside each fault handler USER CODE block (register-level TIM5 stop chosen over HAL — HAL unsafe when stack may be corrupt). Applied to HardFault, MemManage, BusFault, UsageFault. |
| 4 | MEDIUM | ms5837_init failure leaves `pressure_valid = true` | `Core/Src/main.c` | Added `else { sensor_data.pressure.pressure_valid = false; }` branch to prevent phantom depth timer on sensor-absent startup. |
| 5 | MEDIUM | int32 overflow in depth calculation | `Application/User/Core/pressure_sensor.c:106` | Changed to `(int32_t)(((int64_t)delta_pressure_mbar * 995) / 10000)` to prevent overflow near the sensor's 30-bar limit. |
| 6 | MEDIUM | `button_get_event()` non-atomic read-clear | `Application/User/Core/button.c:71` | Wrapped read-clear pair in `__disable_irq()` / `__enable_irq()`. |
| 7 | MEDIUM | ADC4 torn read | `Core/Src/main.c` | Replaced separate `ADC4_VAL[0]` / `ADC4_VAL[1]` accesses with an atomic copy of both values under `__disable_irq()` before calling `sensor_data_update()`. |
| 8 | MEDIUM | `calibrate_sensor()` missing bounds check | `Application/User/Core/calibration.c:19` | Added `if (SensorID >= (SENSOR_COUNT - 2U)) return;` as the first statement. |
| 9 | MEDIUM | 512-byte stack array in `ext_cal_iterate()` | `Application/User/Core/ext_flash_storage.c:547` | Changed `entry_ref_t valid[64]` to `static entry_ref_t valid[64]`. BSS increased by 512 bytes to 57,396 bytes (well within 128 KB RAM). |
| 10 | LOW | `MAX_STABILITY_WAIT` comment misleading | `Application/User/Core/sensor.c:45` | Updated comment to `/* Intentionally 0 — no extra wait beyond MIN_WARMUP_STEPS */`. |
| 11 | LOW | Unused `something` global | `Core/Src/main.c:77` | Deleted. |
| 12 | LOW | Duplicate include guard in `sensor.h` | `Application/User/Core/sensor.h:120-125` | Removed the trailing empty `#ifndef SENSOR_H_ / #define SENSOR_H_ / #endif` block. |
| 13 | LOW | Unused `vbias_effective_mv`, `vbias_counts_for_adc2` | `Core/Src/main.c:109-110` | Confirmed no references in any `.c` file beyond their declarations. Both deleted. |
| 15 | LOW | No PROM CRC validation in MS5837 driver | `Application/User/Core/ms5837.c` | Implemented `static uint8_t ms5837_crc4(const uint16_t *prom)` per MS5837 datasheet §2.4. Called at the end of `ms5837_read_prom()`; returns `MS5837_ERROR_CRC` on mismatch. `MS5837_ERROR_CRC` was already defined in `ms5837.h:70`. |

### No action taken

| # | Severity | Finding | Reason |
|---|---|---|---|
| 14 | LOW | `filter_step_sensor()` complexity ~12 | Below the action threshold of 15. No change. |

### Post-remediation build

```
text     data      bss      dec
214500    148    57396   272044   stm32g474_PPO_Display.elf
```

Build: clean, no errors, no warnings. RAM headroom: ~73 KB remaining.

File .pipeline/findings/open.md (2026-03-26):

# Open Findings

<!-- Generated: 2026-03-26_061548 -->
<!-- DO NOT EDIT MANUALLY — regenerated by analysis pipeline -->
<!-- To suppress a finding, move its block to suppressed.md with justification -->

**Status:** 30 findings require review

---

## Finding 1

<!-- fingerprint: clang-tidy|Core/Src/main.c|bugprone-narrowing-conversions -->
- **Severity:** HIGH
- **Tool:** clang-tidy
- **Check:** `bugprone-narrowing-conversions`
- **Location:** `Core/Src/main.c:766`
- **Message:** narrowing conversion from 'int' to signed type 'int8_t' (aka 'signed char') is implementation-defined
- **Status:** OPEN
- **Resolution:** *pending*

---

## Finding 2

<!-- fingerprint: clang-tidy|STM32CubeIDE/Application/User/Core/dive_log.c|clang-analyzer-security.insecureAPI.DeprecatedOrUnsafeBufferHandling -->
- **Severity:** HIGH
- **Tool:** clang-tidy
- **Check:** `clang-analyzer-security.insecureAPI.DeprecatedOrUnsafeBufferHandling`
- **Location:** `STM32CubeIDE/Application/User/Core/dive_log.c:109`
- **Message:** Call to function 'memset' is insecure as it does not provide security checks introduced in the C11 standard. Replace with analogous functions that support length arguments or provides boundary checks such as 'memset_s' in case of C11
- **Status:** OPEN
- **Resolution:** *pending*

---

## Finding 3

<!-- fingerprint: clang-tidy|STM32CubeIDE/Application/User/Core/ext_flash_storage.c|clang-analyzer-security.insecureAPI.DeprecatedOrUnsafeBufferHandling -->
- **Severity:** HIGH
- **Tool:** clang-tidy
- **Check:** `clang-analyzer-security.insecureAPI.DeprecatedOrUnsafeBufferHandling`
- **Location:** `STM32CubeIDE/Application/User/Core/ext_flash_storage.c:146`
- **Message:** Call to function 'memset' is insecure as it does not provide security checks introduced in the C11 standard. Replace with analogous functions that support length arguments or provides boundary checks such as 'memset_s' in case of C11
- **Status:** OPEN
- **Resolution:** *pending*

---

## Finding 4

<!-- fingerprint: clang-tidy|STM32CubeIDE/Application/User/Core/screens/screen_calibration.c|clang-analyzer-security.insecureAPI.DeprecatedOrUnsafeBufferHandling -->
- **Severity:** HIGH
- **Tool:** clang-tidy
- **Check:** `clang-analyzer-security.insecureAPI.DeprecatedOrUnsafeBufferHandling`
- **Location:** `STM32CubeIDE/Application/User/Core/screens/screen_calibration.c:518`
- **Message:** Call to function 'snprintf' is insecure as it does not provide security checks introduced in the C11 standard. Replace with analogous functions that support length arguments or provides boundary checks such as 'snprintf_s' in case of C11
- **Status:** OPEN
- **Resolution:** *pending*

---

## Finding 5

<!-- fingerprint: clang-tidy|STM32CubeIDE/Application/User/Core/screens/screen_dive_log.c|clang-analyzer-security.insecureAPI.DeprecatedOrUnsafeBufferHandling -->
- **Severity:** HIGH
- **Tool:** clang-tidy
- **Check:** `clang-analyzer-security.insecureAPI.DeprecatedOrUnsafeBufferHandling`
- **Location:** `STM32CubeIDE/Application/User/Core/screens/screen_dive_log.c:133`
- **Message:** Call to function 'snprintf' is insecure as it does not provide security checks introduced in the C11 standard. Replace with analogous functions that support length arguments or provides boundary checks such as 'snprintf_s' in case of C11
- **Status:** OPEN
- **Resolution:** *pending*

---

## Finding 6

<!-- fingerprint: clang-tidy|STM32CubeIDE/Application/User/Core/screens/screen_dive_log.c|bugprone-narrowing-conversions -->
- **Severity:** HIGH
- **Tool:** clang-tidy
- **Check:** `bugprone-narrowing-conversions`
- **Location:** `STM32CubeIDE/Application/User/Core/screens/screen_dive_log.c:265`
- **Message:** narrowing conversion from 'int' to signed type 'lv_coord_t' (aka 'short') is implementation-defined
- **Status:** OPEN
- **Resolution:** *pending*

---

## Finding 7

<!-- fingerprint: clang-tidy|STM32CubeIDE/Application/User/Core/screens/screen_sensor_data.c|clang-analyzer-security.insecureAPI.DeprecatedOrUnsafeBufferHandling -->
- **Severity:** HIGH
- **Tool:** clang-tidy
- **Check:** `clang-analyzer-security.insecureAPI.DeprecatedOrUnsafeBufferHandling`
- **Location:** `STM32CubeIDE/Application/User/Core/screens/screen_sensor_data.c:114`
- **Message:** Call to function 'snprintf' is insecure as it does not provide security checks introduced in the C11 standard. Replace with analogous functions that support length arguments or provides boundary checks such as 'snprintf_s' in case of C11
- **Status:** OPEN
- **Resolution:** *pending*

---

## Finding 8

<!-- fingerprint: clang-tidy|STM32CubeIDE/Application/User/Core/screens/screen_settings.c|clang-analyzer-security.insecureAPI.DeprecatedOrUnsafeBufferHandling -->
- **Severity:** HIGH
- **Tool:** clang-tidy
- **Check:** `clang-analyzer-security.insecureAPI.DeprecatedOrUnsafeBufferHandling`
- **Location:** `STM32CubeIDE/Application/User/Core/screens/screen_settings.c:95`
- **Message:** Call to function 'snprintf' is insecure as it does not provide security checks introduced in the C11 standard. Replace with analogous functions that support length arguments or provides boundary checks such as 'snprintf_s' in case of C11
- **Status:** OPEN
- **Resolution:** *pending*

---

## Finding 9

<!-- fingerprint: clang-tidy|STM32CubeIDE/Application/User/Core/sensor.c|bugprone-implicit-widening-of-multiplication-result -->
- **Severity:** HIGH
- **Tool:** clang-tidy
- **Check:** `bugprone-implicit-widening-of-multiplication-result`
- **Location:** `STM32CubeIDE/Application/User/Core/sensor.c:205`
- **Message:** performing an implicit widening conversion to type 'unsigned long' of a multiplication performed in type 'int'
- **Status:** OPEN
- **Resolution:** *pending*

---

## Finding 10

<!-- fingerprint: clang-tidy|STM32CubeIDE/Application/User/Core/sensor.c|bugprone-narrowing-conversions -->
- **Severity:** HIGH
- **Tool:** clang-tidy
- **Check:** `bugprone-narrowing-conversions`
- **Location:** `STM32CubeIDE/Application/User/Core/sensor.c:206`
- **Message:** narrowing conversion from 'unsigned int' to signed type 'int32_t' (aka 'int') is implementation-defined
- **Status:** OPEN
- **Resolution:** *pending*

---

## Finding 11

<!-- fingerprint: clang-tidy|STM32CubeIDE/Application/User/Core/sensor_diagnostics.c|clang-analyzer-security.insecureAPI.DeprecatedOrUnsafeBufferHandling -->
- **Severity:** HIGH
- **Tool:** clang-tidy
- **Check:** `clang-analyzer-security.insecureAPI.DeprecatedOrUnsafeBufferHandling`
- **Location:** `STM32CubeIDE/Application/User/Core/sensor_diagnostics.c:192`
- **Message:** Call to function 'memset' is insecure as it does not provide security checks introduced in the C11 standard. Replace with analogous functions that support length arguments or provides boundary checks such as 'memset_s' in case of C11
- **Status:** OPEN
- **Resolution:** *pending*

---

## Finding 12

<!-- fingerprint: clang-tidy|STM32CubeIDE/Application/User/Core/w25q128.c|clang-analyzer-security.insecureAPI.DeprecatedOrUnsafeBufferHandling -->
- **Severity:** HIGH
- **Tool:** clang-tidy
- **Check:** `clang-analyzer-security.insecureAPI.DeprecatedOrUnsafeBufferHandling`
- **Location:** `STM32CubeIDE/Application/User/Core/w25q128.c:216`
- **Message:** Call to function 'memset' is insecure as it does not provide security checks introduced in the C11 standard. Replace with analogous functions that support length arguments or provides boundary checks such as 'memset_s' in case of C11
- **Status:** OPEN
- **Resolution:** *pending*

---

## Finding 13

<!-- fingerprint: flawfinder|STM32CubeIDE/Application/User/Core/dive_log.c:133|buffer -->
- **Severity:** MEDIUM
- **Tool:** flawfinder
- **Check:** `buffer`
- **Location:** `STM32CubeIDE/Application/User/Core/dive_log.c:133:5`
- **Message:** memcpy:Does not check for buffer overflows when copying to destination (CWE-120).  Make sure destination can always hold the source data.
- **Detail:** Risk level: 2/5
- **Status:** OPEN
- **Resolution:** *pending*

---

## Finding 14

<!-- fingerprint: flawfinder|STM32CubeIDE/Application/User/Core/screens/screen_dive_log.c:125|buffer -->
- **Severity:** MEDIUM
- **Tool:** flawfinder
- **Check:** `buffer`
- **Location:** `STM32CubeIDE/Application/User/Core/screens/screen_dive_log.c:125:12`
- **Message:** char:Statically-sized arrays can be improperly restricted, leading to potential overflows or other issues (CWE-119!/CWE-120).  Perform bounds checking, use functions that limit length, or ensure that the size is larger than the maximum possible length.
- **Detail:** Risk level: 2/5
- **Status:** OPEN
- **Resolution:** *pending*

---

## Finding 15

<!-- fingerprint: flawfinder|STM32CubeIDE/Application/User/Core/screens/screen_dive_log.c:158|buffer -->
- **Severity:** MEDIUM
- **Tool:** flawfinder
- **Check:** `buffer`
- **Location:** `STM32CubeIDE/Application/User/Core/screens/screen_dive_log.c:158:12`
- **Message:** char:Statically-sized arrays can be improperly restricted, leading to potential overflows or other issues (CWE-119!/CWE-120).  Perform bounds checking, use functions that limit length, or ensure that the size is larger than the maximum possible length.
- **Detail:** Risk level: 2/5
- **Status:** OPEN
- **Resolution:** *pending*

---

## Finding 16

<!-- fingerprint: flawfinder|STM32CubeIDE/Application/User/Core/screens/screen_dive_log.c:159|buffer -->
- **Severity:** MEDIUM
- **Tool:** flawfinder
- **Check:** `buffer`
- **Location:** `STM32CubeIDE/Application/User/Core/screens/screen_dive_log.c:159:12`
- **Message:** char:Statically-sized arrays can be improperly restricted, leading to potential overflows or other issues (CWE-119!/CWE-120).  Perform bounds checking, use functions that limit length, or ensure that the size is larger than the maximum possible length.
- **Detail:** Risk level: 2/5
- **Status:** OPEN
- **Resolution:** *pending*

---

## Finding 17

<!-- fingerprint: flawfinder|STM32CubeIDE/Application/User/Core/screens/screen_main.c:761|buffer -->
- **Severity:** MEDIUM
- **Tool:** flawfinder
- **Check:** `buffer`
- **Location:** `STM32CubeIDE/Application/User/Core/screens/screen_main.c:761:9`
- **Message:** char:Statically-sized arrays can be improperly restricted, leading to potential overflows or other issues (CWE-119!/CWE-120).  Perform bounds checking, use functions that limit length, or ensure that the size is larger than the maximum possible length.
- **Detail:** Risk level: 2/5
- **Status:** OPEN
- **Resolution:** *pending*

---

## Finding 18

<!-- fingerprint: flawfinder|STM32CubeIDE/Application/User/Core/screens/screen_main.c:780|buffer -->
- **Severity:** MEDIUM
- **Tool:** flawfinder
- **Check:** `buffer`
- **Location:** `STM32CubeIDE/Application/User/Core/screens/screen_main.c:780:9`
- **Message:** char:Statically-sized arrays can be improperly restricted, leading to potential overflows or other issues (CWE-119!/CWE-120).  Perform bounds checking, use functions that limit length, or ensure that the size is larger than the maximum possible length.
- **Detail:** Risk level: 2/5
- **Status:** OPEN
- **Resolution:** *pending*

---

## Finding 19

<!-- fingerprint: flawfinder|STM32CubeIDE/Application/User/Core/screens/screen_sensor_data.c:111|buffer -->
- **Severity:** MEDIUM
- **Tool:** flawfinder
- **Check:** `buffer`
- **Location:** `STM32CubeIDE/Application/User/Core/screens/screen_sensor_data.c:111:12`
- **Message:** char:Statically-sized arrays can be improperly restricted, leading to potential overflows or other issues (CWE-119!/CWE-120).  Perform bounds checking, use functions that limit length, or ensure that the size is larger than the maximum possible length.
- **Detail:** Risk level: 2/5
- **Status:** OPEN
- **Resolution:** *pending*

---

## Finding 20

<!-- fingerprint: lizard|Core/Src/main.c|complexity(warning: main) -->
- **Severity:** MEDIUM
- **Tool:** lizard
- **Check:** `complexity(warning: main)`
- **Location:** `Core/Src/main.c:517`
- **Message:** Cyclomatic complexity 27 exceeds threshold 15
- **Detail:** Function: warning: main
- **Status:** OPEN
- **Resolution:** *pending*

---

## Finding 21

<!-- fingerprint: lizard|STM32CubeIDE/Application/User/Core/screens/screen_calibration.c|complexity(warning: build_screen_content) -->
- **Severity:** MEDIUM
- **Tool:** lizard
- **Check:** `complexity(warning: build_screen_content)`
- **Location:** `STM32CubeIDE/Application/User/Core/screens/screen_calibration.c:56`
- **Message:** Function length 228 lines exceeds threshold 75
- **Detail:** Function: warning: build_screen_content
- **Status:** OPEN
- **Resolution:** *pending*

---

## Finding 22

<!-- fingerprint: lizard|STM32CubeIDE/Application/User/Core/screens/screen_calibration.c|complexity(warning: screen_calibration_update) -->
- **Severity:** MEDIUM
- **Tool:** lizard
- **Check:** `complexity(warning: screen_calibration_update)`
- **Location:** `STM32CubeIDE/Application/User/Core/screens/screen_calibration.c:513`
- **Message:** Cyclomatic complexity 22 exceeds threshold 15
- **Detail:** Function: warning: screen_calibration_update
- **Status:** OPEN
- **Resolution:** *pending*

---

## Finding 23

<!-- fingerprint: lizard|STM32CubeIDE/Application/User/Core/screens/screen_calibration.c|complexity(warning: screen_calibration_on_button) -->
- **Severity:** MEDIUM
- **Tool:** lizard
- **Check:** `complexity(warning: screen_calibration_on_button)`
- **Location:** `STM32CubeIDE/Application/User/Core/screens/screen_calibration.c:634`
- **Message:** Cyclomatic complexity 21 exceeds threshold 15
- **Detail:** Function: warning: screen_calibration_on_button
- **Status:** OPEN
- **Resolution:** *pending*

---

## Finding 24

<!-- fingerprint: lizard|STM32CubeIDE/Application/User/Core/screens/screen_main.c|complexity(warning: build_screen_content) -->
- **Severity:** MEDIUM
- **Tool:** lizard
- **Check:** `complexity(warning: build_screen_content)`
- **Location:** `STM32CubeIDE/Application/User/Core/screens/screen_main.c:87`
- **Message:** Function length 309 lines exceeds threshold 75
- **Detail:** Function: warning: build_screen_content
- **Status:** OPEN
- **Resolution:** *pending*

---

## Finding 25

<!-- fingerprint: lizard|STM32CubeIDE/Application/User/Core/screens/screen_main.c|complexity(warning: screen_main_update) -->
- **Severity:** MEDIUM
- **Tool:** lizard
- **Check:** `complexity(warning: screen_main_update)`
- **Location:** `STM32CubeIDE/Application/User/Core/screens/screen_main.c:519`
- **Message:** Cyclomatic complexity 46 exceeds threshold 15
- **Detail:** Function: warning: screen_main_update
- **Status:** OPEN
- **Resolution:** *pending*

---

## Finding 26

<!-- fingerprint: lizard|STM32CubeIDE/Application/User/Core/dive_log.c|complexity(warning: dive_log_tick_1hz) -->
- **Severity:** MEDIUM
- **Tool:** lizard
- **Check:** `complexity(warning: dive_log_tick_1hz)`
- **Location:** `STM32CubeIDE/Application/User/Core/dive_log.c:291`
- **Message:** Cyclomatic complexity 36 exceeds threshold 15
- **Detail:** Function: warning: dive_log_tick_1hz
- **Status:** OPEN
- **Resolution:** *pending*

---

## Finding 27

<!-- fingerprint: lizard|STM32CubeIDE/Application/User/Core/dive_log.c|complexity(warning: dive_log_iterate) -->
- **Severity:** MEDIUM
- **Tool:** lizard
- **Check:** `complexity(warning: dive_log_iterate)`
- **Location:** `STM32CubeIDE/Application/User/Core/dive_log.c:401`
- **Message:** Cyclomatic complexity 19 exceeds threshold 15
- **Detail:** Function: warning: dive_log_iterate
- **Status:** OPEN
- **Resolution:** *pending*

---

## Finding 28

<!-- fingerprint: lizard|STM32CubeIDE/Application/User/Core/ext_flash_storage.c|complexity(warning: ext_cal_iterate) -->
- **Severity:** MEDIUM
- **Tool:** lizard
- **Check:** `complexity(warning: ext_cal_iterate)`
- **Location:** `STM32CubeIDE/Application/User/Core/ext_flash_storage.c:535`
- **Message:** Cyclomatic complexity 16 exceeds threshold 15
- **Detail:** Function: warning: ext_cal_iterate
- **Status:** OPEN
- **Resolution:** *pending*

---

## Finding 29

<!-- fingerprint: lizard|STM32CubeIDE/Application/User/Core/screen_manager.c|complexity(warning: screen_manager_handle_button) -->
- **Severity:** MEDIUM
- **Tool:** lizard
- **Check:** `complexity(warning: screen_manager_handle_button)`
- **Location:** `STM32CubeIDE/Application/User/Core/screen_manager.c:94`
- **Message:** Cyclomatic complexity 17 exceeds threshold 15
- **Detail:** Function: warning: screen_manager_handle_button
- **Status:** OPEN
- **Resolution:** *pending*

---

## Finding 30

<!-- fingerprint: lizard|STM32CubeIDE/Application/User/Core/sensor.c|complexity(warning: sensor_data_update) -->
- **Severity:** MEDIUM
- **Tool:** lizard
- **Check:** `complexity(warning: sensor_data_update)`
- **Location:** `STM32CubeIDE/Application/User/Core/sensor.c:182`
- **Message:** Cyclomatic complexity 23 exceeds threshold 15
- **Detail:** Function: warning: sensor_data_update
- **Status:** OPEN
- **Resolution:** *pending*

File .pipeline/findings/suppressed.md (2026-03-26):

# Suppressed Findings

<!-- Add findings here that are intentionally accepted -->
<!-- Each must include a fingerprint comment and justification -->

---

## Suppressed 1

<!-- fingerprint: clang-tidy|Drivers/CMSIS/Device/ST/STM32G4xx/Include/stm32g4xx.h|clang-diagnostic-error -->
- **Severity:** CRITICAL
- **Tool:** clang-tidy
- **Check:** `clang-diagnostic-error`
- **Location:** `Drivers/CMSIS/Device/ST/STM32G4xx/Include/stm32g4xx.h:111`
- **Message:** 'stm32g431xx.h' file not found
- **Justification:** clang-tidy misconfiguration — this project targets STM32G474, not G431. clang-tidy is resolving to the wrong device header. The firmware builds correctly against the proper target. Fix by updating the clang-tidy include path config to define `STM32G474xx`.

---

## Suppressed 2

<!-- fingerprint: clang-tidy|STM32CubeIDE/Application/User/Core/syscalls.c|clang-diagnostic-error -->
- **Severity:** CRITICAL
- **Tool:** clang-tidy
- **Check:** `clang-diagnostic-error`
- **Location:** `STM32CubeIDE/Application/User/Core/syscalls.c:102`
- **Message:** use of undeclared identifier 'S_IFCHR'
- **Justification:** Cascading false positive from Suppressed 1 (wrong device header breaks the POSIX include chain). `S_IFCHR` is defined in `<sys/stat.h>` which depends on the correct STM32 device header being resolved. Not a real firmware bug.

---

## Suppressed 3

<!-- fingerprint: clang-tidy|STM32CubeIDE/Application/User/Core/sysmem.c|clang-diagnostic-error -->
- **Severity:** CRITICAL
- **Tool:** clang-tidy
- **Check:** `clang-diagnostic-error`
- **Location:** `STM32CubeIDE/Application/User/Core/sysmem.c:30`
- **Message:** use of undeclared identifier 'NULL'
- **Justification:** Cascading false positive from Suppressed 1 (wrong device header breaks `<stddef.h>` resolution). `NULL` is correctly defined in the actual build environment. Not a real firmware bug.

---

## Suppressed 4

<!-- fingerprint: clang-tidy|Core/Src/stm32g4xx_hal_msp.c|bugprone-branch-clone -->
- **Severity:** HIGH
- **Tool:** clang-tidy
- **Check:** `bugprone-branch-clone`
- **Location:** `Core/Src/stm32g4xx_hal_msp.c:324`
- **Message:** repeated branch body in conditional chain
- **Justification:** CubeMX-generated file. Pattern is intentional — ST generates symmetric MSP init/deinit branches for multiple peripheral instances. Not user-editable without risking regeneration conflicts.

---

## Suppressed 5

<!-- fingerprint: clang-tidy|Core/Src/system_stm32g4xx.c|bugprone-branch-clone -->
- **Severity:** HIGH
- **Tool:** clang-tidy
- **Check:** `bugprone-branch-clone`
- **Location:** `Core/Src/system_stm32g4xx.c:251`
- **Message:** if with identical then and else branches
- **Justification:** CubeMX-generated file. ST's clock configuration code uses symmetric if/else for conditional compilation placeholders. Not user-editable.

---

## Suppressed 6

<!-- fingerprint: clang-tidy|STM32CubeIDE/Application/User/Core/screens/screen_main.c|clang-analyzer-security.insecureAPI.DeprecatedOrUnsafeBufferHandling -->
- **Severity:** HIGH
- **Tool:** clang-tidy
- **Check:** `clang-analyzer-security.insecureAPI.DeprecatedOrUnsafeBufferHandling`
- **Location:** `STM32CubeIDE/Application/User/Core/screens/screen_main.c:497`
- **Message:** Call to function 'snprintf' is insecure as it does not provide security checks introduced in the C11 standard.
- **Justification:** False positive on embedded target. `snprintf_s` is not available in ARM newlib. `snprintf` with an explicit size argument IS the bounds-safe function on this platform. No user input involved — format strings are compile-time constants.

---

## Suppressed 7

<!-- fingerprint: clang-tidy|STM32CubeIDE/Application/User/Core/syscalls.c|bugprone-reserved-identifier -->
- **Severity:** HIGH
- **Tool:** clang-tidy
- **Check:** `bugprone-reserved-identifier`
- **Location:** `STM32CubeIDE/Application/User/Core/syscalls.c:35`
- **Message:** declaration uses identifier '__io_putchar', which is a reserved identifier
- **Justification:** ST-generated syscalls boilerplate. `__io_putchar` is the standard ST weak symbol for retargeting `printf` to UART. This is the intended pattern for this toolchain.

---

## Suppressed 8

<!-- fingerprint: clang-tidy|STM32CubeIDE/Application/User/Core/syscalls.c|bugprone-narrowing-conversions -->
- **Severity:** HIGH
- **Tool:** clang-tidy
- **Check:** `bugprone-narrowing-conversions`
- **Location:** `STM32CubeIDE/Application/User/Core/syscalls.c:74`
- **Message:** narrowing conversion from 'int' to signed type 'char' is implementation-defined
- **Justification:** ST-generated syscalls boilerplate. Standard newlib retargeting pattern; value is always in `[0, 255]` range by POSIX contract.

---

## Suppressed 9

<!-- fingerprint: clang-tidy|STM32CubeIDE/Application/User/Core/syscalls.c|readability-non-const-parameter -->
- **Severity:** HIGH
- **Tool:** clang-tidy
- **Check:** `readability-non-const-parameter`
- **Location:** `STM32CubeIDE/Application/User/Core/syscalls.c:120`
- **Message:** pointer parameter 'path' can be pointer to const
- **Justification:** ST-generated syscalls boilerplate. Signature must match the POSIX `_stat` declaration which does not use `const`.

---

## Suppressed 10

<!-- fingerprint: clang-tidy|STM32CubeIDE/Application/User/Core/sysmem.c|bugprone-reserved-identifier -->
- **Severity:** HIGH
- **Tool:** clang-tidy
- **Check:** `bugprone-reserved-identifier`
- **Location:** `STM32CubeIDE/Application/User/Core/sysmem.c:30`
- **Message:** declaration uses identifier '__sbrk_heap_end', which is a reserved identifier
- **Justification:** ST-generated sysmem boilerplate. `__sbrk_heap_end` is the standard ST/newlib heap tracking variable for the `_sbrk` syscall implementation.

---

## Suppressed 11

<!-- fingerprint: clang-tidy|STM32CubeIDE/Application/User/Core/sysmem.c|clang-diagnostic-pointer-to-int-cast -->
- **Severity:** HIGH
- **Tool:** clang-tidy
- **Check:** `clang-diagnostic-pointer-to-int-cast`
- **Location:** `STM32CubeIDE/Application/User/Core/sysmem.c:58`
- **Message:** cast to smaller integer type 'uint32_t' from 'uint8_t *'
- **Justification:** ST-generated sysmem boilerplate. On Cortex-M4 (32-bit), pointer and `uint32_t` are the same size. This cast is required for the `_sbrk` heap boundary arithmetic and is standard practice in ARM newlib ports.

---

## Suppressed 12

<!-- fingerprint: clang-tidy|STM32CubeIDE/Application/User/Core/sysmem.c|clang-diagnostic-int-to-pointer-cast -->
- **Severity:** HIGH
- **Tool:** clang-tidy
- **Check:** `clang-diagnostic-int-to-pointer-cast`
- **Location:** `STM32CubeIDE/Application/User/Core/sysmem.c:59`
- **Message:** cast to 'uint8_t *' from smaller integer type 'uint32_t'
- **Justification:** ST-generated sysmem boilerplate. Paired with Suppressed 11 — same `_sbrk` heap arithmetic pattern. Valid on 32-bit Cortex-M4.

---

## Suppressed 13

<!-- fingerprint: cppcheck|STM32CubeIDE/Application/User/Core/syscalls.c|constParameterPointer -->
- **Severity:** MEDIUM
- **Tool:** cppcheck
- **Check:** `constParameterPointer`
- **Location:** `STM32CubeIDE/Application/User/Core/syscalls.c:80`
- **Message:** Parameter 'ptr' can be declared as pointer to const
- **Justification:** ST-generated syscalls boilerplate. Signature must match the POSIX `_write` syscall declaration.

---

## Suppressed 14

<!-- fingerprint: flawfinder|STM32CubeIDE/Application/User/Core/syscalls.c:39|buffer -->
- **Severity:** MEDIUM
- **Tool:** flawfinder
- **Check:** `buffer`
- **Location:** `STM32CubeIDE/Application/User/Core/syscalls.c:39:1`
- **Message:** char:Statically-sized arrays can be improperly restricted
- **Justification:** ST-generated syscalls boilerplate. Fixed-size UART retargeting buffer; size is appropriate for the use case and not driven by external input.

---

## Suppressed 15

<!-- fingerprint: cppcheck|STM32CubeIDE/Application/User/Core/screens/screen_calibration.c|knownConditionTrueFalse -->
- **Severity:** MEDIUM
- **Tool:** cppcheck
- **Check:** `knownConditionTrueFalse`
- **Location:** `STM32CubeIDE/Application/User/Core/screens/screen_calibration.c:66`
- **Message:** Same expression on both sides of '|' because 'LV_PART_MAIN' and 'LV_STATE_DEFAULT' represent the same value.
- **Justification:** Idiomatic LVGL v8 style. `LV_PART_MAIN | LV_STATE_DEFAULT` is the canonical selector expression used throughout LVGL examples and documentation. Both constants are 0 by design; the expression evaluates to 0 which is the correct default selector. Not a logic error.

---

## Suppressed 16

<!-- fingerprint: cppcheck|STM32CubeIDE/Application/User/Core/screens/screen_menu.c|knownConditionTrueFalse -->
- **Severity:** MEDIUM
- **Tool:** cppcheck
- **Check:** `knownConditionTrueFalse`
- **Location:** `STM32CubeIDE/Application/User/Core/screens/screen_menu.c:58`
- **Message:** Same expression on both sides of '|' because 'LV_PART_MAIN' and 'LV_STATE_DEFAULT' represent the same value.
- **Justification:** Same as Suppressed 15 — idiomatic LVGL v8 style selector expression.

---

## Suppressed 17

<!-- fingerprint: cppcheck|STM32CubeIDE/Application/User/Core/warning.c|knownConditionTrueFalse -->
- **Severity:** MEDIUM
- **Tool:** cppcheck
- **Check:** `knownConditionTrueFalse`
- **Location:** `STM32CubeIDE/Application/User/Core/warning.c:301`
- **Message:** Same expression on both sides of '|' because 'LV_PART_MAIN' and 'LV_STATE_DEFAULT' represent the same value.
- **Justification:** Same as Suppressed 15 — idiomatic LVGL v8 style selector expression.

---

## Suppressed 18

<!-- fingerprint: cppcheck|Core/Src/main.c|constParameterPointer -->
- **Severity:** MEDIUM
- **Tool:** cppcheck
- **Check:** `constParameterPointer`
- **Location:** `Core/Src/main.c:252`
- **Message:** Parameter 'htim' can be declared as pointer to const
- **Justification:** `HAL_TIM_PeriodElapsedCallback` is a HAL weak-symbol override. The signature must exactly match the HAL declaration (`TIM_HandleTypeDef *htim`). Adding `const` would create a different function prototype that would NOT override the weak symbol, silently breaking the callback.

---

## Suppressed 19

<!-- fingerprint: cppcheck|Core/Src/stm32g4xx_hal_msp.c|funcArgNamesDifferent -->
- **Severity:** MEDIUM
- **Tool:** cppcheck
- **Check:** `funcArgNamesDifferent`
- **Location:** `Core/Src/stm32g4xx_hal_msp.c:802`
- **Message:** Function 'HAL_TIM_Base_MspInit' argument 1 names different: declaration 'htim' definition 'htim_base'.
- **Justification:** CubeMX-generated code. ST uses `htim_base` as the local parameter name in the MSP init definition while the HAL header uses `htim`. This is an ST naming inconsistency in generated code, not a bug.

---

## Suppressed 20

<!-- fingerprint: cppcheck|Core/Src/stm32g4xx_hal_msp.c|constParameterPointer -->
- **Severity:** MEDIUM
- **Tool:** cppcheck
- **Check:** `constParameterPointer`
- **Location:** `Core/Src/stm32g4xx_hal_msp.c:431`
- **Message:** Parameter 'hi2c' can be declared as pointer to const
- **Justification:** CubeMX-generated HAL MSP hook. Signature must match the HAL `__weak` declaration exactly. Not modifiable without risking CubeMX regeneration conflicts.

---

## Suppressed 21

<!-- fingerprint: cppcheck|STM32CubeIDE/Application/User/Core/ext_flash_storage.c|knownConditionTrueFalse -->
- **Severity:** MEDIUM
- **Tool:** cppcheck
- **Check:** `knownConditionTrueFalse`
- **Location:** `STM32CubeIDE/Application/User/Core/ext_flash_storage.c:340`
- **Message:** Condition 'next_seq==0U' is always false
- **Justification:** Intentional defensive guard against UINT32_MAX sequence counter wrap-around: `if (next_seq == 0U) next_seq = 1U`. cppcheck proves it can't happen given static analysis paths, but the guard is retained as defensive coding for long-running deployments where the sequence counter could theoretically reach UINT32_MAX after ~4 billion writes.

---

## Suppressed 22

<!-- fingerprint: cppcheck|STM32CubeIDE/Application/User/Core/screens/screen_main.c|knownConditionTrueFalse -->
- **Severity:** MEDIUM
- **Tool:** cppcheck
- **Check:** `knownConditionTrueFalse`
- **Location:** `STM32CubeIDE/Application/User/Core/screens/screen_main.c:649`
- **Message:** Condition 'num_sensors>3' is always false
- **Justification:** `SENSOR_COUNT` is a compile-time enum constant (=5). `num_sensors = SENSOR_COUNT - 2 = 3` always. The clamp `if (num_sensors > 3) num_sensors = 3` is dead code but documents the architectural constraint (exactly 3 O2 sensors). Retained for future maintainability when SENSOR_COUNT changes.

---

## Suppressed 23

<!-- fingerprint: cppcheck|STM32CubeIDE/Application/User/Core/st7789v.c|constVariable -->
- **Severity:** MEDIUM
- **Tool:** cppcheck
- **Check:** `constVariable`
- **Location:** `STM32CubeIDE/Application/User/Core/st7789v.c:42`
- **Message:** Variable 'param_madctl' can be declared as const array
- **Justification:** `param_madctl` is passed directly to `HAL_SPI_Transmit(SPI_HandleTypeDef*, uint8_t*, ...)` which requires a non-const `uint8_t*`. Adding `const` would require an unsafe cast to satisfy the HAL API.

---

## Suppressed 24

<!-- fingerprint: cppcheck|STM32CubeIDE/Application/User/Core/w25q128.c|constParameterPointer -->
- **Severity:** MEDIUM
- **Tool:** cppcheck
- **Check:** `constParameterPointer`
- **Location:** `STM32CubeIDE/Application/User/Core/w25q128.c:20`
- **Message:** Parameter 'buf' can be declared as pointer to const
- **Justification:** `spi_tx()` passes `buf` directly to `HAL_SPI_Transmit(SPI_HandleTypeDef*, uint8_t*, ...)`. The HAL API requires non-const. Adding `const` to the wrapper parameter would require a discarding cast.

---

## Suppressed 25

<!-- fingerprint: cppcheck|STM32CubeIDE/Application/User/Core/w25q128.c|constVariable -->
- **Severity:** MEDIUM
- **Tool:** cppcheck
- **Check:** `constVariable`
- **Location:** `STM32CubeIDE/Application/User/Core/w25q128.c:111`
- **Message:** Variable 'tx' can be declared as const array
- **Justification:** `tx` is passed to `HAL_SPI_TransmitReceive(SPI_HandleTypeDef*, uint8_t* pTxData, ...)`. The HAL API requires non-const `pTxData`. Declaring `tx` as `const` would require an unsafe cast.

---

## Suppressed 26

<!-- fingerprint: flawfinder|STM32CubeIDE/Application/User/Core/ext_flash_storage.c:172|buffer -->
- **Severity:** MEDIUM
- **Tool:** flawfinder
- **Check:** `buffer`
- **Location:** `STM32CubeIDE/Application/User/Core/ext_flash_storage.c:172:5`
- **Message:** memcpy — does not check for buffer overflows (CWE-120)
- **Justification:** `memcpy(tmp, buf, EXT_SETTINGS_ENTRY_SIZE)` — both `tmp` and `buf` are declared as `EXT_SETTINGS_ENTRY_SIZE`-byte (28-byte) buffers. Size is a compile-time constant; source and destination are always correctly sized.

---

## Suppressed 27

<!-- fingerprint: flawfinder|STM32CubeIDE/Application/User/Core/ext_flash_storage.c:199|buffer -->
- **Severity:** MEDIUM
- **Tool:** flawfinder
- **Check:** `buffer`
- **Location:** `STM32CubeIDE/Application/User/Core/ext_flash_storage.c:199:5`
- **Message:** memcpy — does not check for buffer overflows (CWE-120)
- **Justification:** Same as Suppressed 26 — `memcpy(tmp, out, EXT_SETTINGS_ENTRY_SIZE)` with matching compile-time-sized buffers.

---

## Suppressed 28

<!-- fingerprint: flawfinder|STM32CubeIDE/Application/User/Core/ext_flash_storage.c:244|buffer -->
- **Severity:** MEDIUM
- **Tool:** flawfinder
- **Check:** `buffer`
- **Location:** `STM32CubeIDE/Application/User/Core/ext_flash_storage.c:244:5`
- **Message:** memcpy — does not check for buffer overflows (CWE-120)
- **Justification:** `memcpy(tmp, buf, EXT_CAL_ENTRY_SIZE)` — both buffers are `EXT_CAL_ENTRY_SIZE`-byte (48-byte) compile-time-sized allocations. No overflow possible.

---

## Suppressed 29

<!-- fingerprint: flawfinder|STM32CubeIDE/Application/User/Core/ext_flash_storage.c:273|buffer -->
- **Severity:** MEDIUM
- **Tool:** flawfinder
- **Check:** `buffer`
- **Location:** `STM32CubeIDE/Application/User/Core/ext_flash_storage.c:273:5`
- **Message:** memcpy — does not check for buffer overflows (CWE-120)
- **Justification:** Same as Suppressed 28 — `memcpy(tmp, buf, EXT_CAL_ENTRY_SIZE)` with matching compile-time-sized buffers.

---

## Suppressed 30

<!-- fingerprint: flawfinder|STM32CubeIDE/Application/User/Core/screens/screen_calibration.c:514|buffer -->
- **Severity:** MEDIUM
- **Tool:** flawfinder
- **Check:** `buffer`
- **Location:** `STM32CubeIDE/Application/User/Core/screens/screen_calibration.c:514:5`
- **Message:** char — statically-sized arrays can be improperly restricted (CWE-119/120)
- **Justification:** Static `char` buffer used with `snprintf(buf, sizeof(buf), ...)`. The `sizeof(buf)` argument bounds all writes to the declared array size. No external input reaches this buffer without truncation.

---

## Suppressed 31

<!-- fingerprint: flawfinder|STM32CubeIDE/Application/User/Core/screens/screen_calibration.c:635|buffer -->
- **Severity:** MEDIUM
- **Tool:** flawfinder
- **Check:** `buffer`
- **Location:** `STM32CubeIDE/Application/User/Core/screens/screen_calibration.c:635:5`
- **Message:** char — statically-sized arrays can be improperly restricted (CWE-119/120)
- **Justification:** Same as Suppressed 30 — static `char` buffer with `snprintf(buf, sizeof(buf), ...)`.

---

## Suppressed 32

<!-- fingerprint: flawfinder|STM32CubeIDE/Application/User/Core/screens/screen_main.c:496|buffer -->
- **Severity:** MEDIUM
- **Tool:** flawfinder
- **Check:** `buffer`
- **Location:** `STM32CubeIDE/Application/User/Core/screens/screen_main.c:496:12`
- **Message:** char — statically-sized arrays can be improperly restricted (CWE-119/120)
- **Justification:** Same as Suppressed 30 — static `char` buffer with `snprintf(buf, sizeof(buf), ...)`.

---

## Suppressed 33

<!-- fingerprint: flawfinder|STM32CubeIDE/Application/User/Core/screens/screen_main.c:526|buffer -->
- **Severity:** MEDIUM
- **Tool:** flawfinder
- **Check:** `buffer`
- **Location:** `STM32CubeIDE/Application/User/Core/screens/screen_main.c:526:5`
- **Message:** char — statically-sized arrays can be improperly restricted (CWE-119/120)
- **Justification:** Same as Suppressed 30 — static `char` buffer with `snprintf(buf, sizeof(buf), ...)`.

---

## Suppressed 34

<!-- fingerprint: flawfinder|STM32CubeIDE/Application/User/Core/screens/screen_main.c:768|buffer -->
- **Severity:** MEDIUM
- **Tool:** flawfinder
- **Check:** `buffer`
- **Location:** `STM32CubeIDE/Application/User/Core/screens/screen_main.c:768:9`
- **Message:** char — statically-sized arrays can be improperly restricted (CWE-119/120)
- **Justification:** Same as Suppressed 30 — static `char` buffer with `snprintf(buf, sizeof(buf), ...)`.

---

## Suppressed 35

<!-- fingerprint: flawfinder|STM32CubeIDE/Application/User/Core/screens/screen_main.c:787|buffer -->
- **Severity:** MEDIUM
- **Tool:** flawfinder
- **Check:** `buffer`
- **Location:** `STM32CubeIDE/Application/User/Core/screens/screen_main.c:787:9`
- **Message:** char — statically-sized arrays can be improperly restricted (CWE-119/120)
- **Justification:** Same as Suppressed 30 — static `char` buffer with `snprintf(buf, sizeof(buf), ...)`.

---

## Suppressed 36

<!-- fingerprint: flawfinder|STM32CubeIDE/Application/User/Core/screens/screen_sensor_data.c:112|buffer -->
- **Severity:** MEDIUM
- **Tool:** flawfinder
- **Check:** `buffer`
- **Location:** `STM32CubeIDE/Application/User/Core/screens/screen_sensor_data.c:112:12`
- **Message:** char — statically-sized arrays can be improperly restricted (CWE-119/120)
- **Justification:** Same as Suppressed 30 — static `char` buffer with `snprintf(buf, sizeof(buf), ...)`.

---

## Suppressed 37

<!-- fingerprint: flawfinder|STM32CubeIDE/Application/User/Core/screens/screen_settings.c:92|buffer -->
- **Severity:** MEDIUM
- **Tool:** flawfinder
- **Check:** `buffer`
- **Location:** `STM32CubeIDE/Application/User/Core/screens/screen_settings.c:92:12`
- **Message:** char — statically-sized arrays can be improperly restricted (CWE-119/120)
- **Justification:** Same as Suppressed 30 — static `char` buffer with `snprintf(buf, sizeof(buf), ...)`.

---

## Suppressed 38

<!-- fingerprint: lizard|Core/Src/stm32g4xx_hal_msp.c|complexity(warning: HAL_ADC_MspInit) -->
- **Severity:** MEDIUM
- **Tool:** lizard
- **Check:** `complexity(warning: HAL_ADC_MspInit)`
- **Location:** `Core/Src/stm32g4xx_hal_msp.c:115`
- **Message:** Cyclomatic complexity 17 exceeds threshold 15
- **Justification:** CubeMX-generated `HAL_ADC_MspInit`. Complexity reflects the number of ADC channels/DMA streams being configured by ST's code generator. Not user-editable.

---

## Suppressed 39

<!-- fingerprint: clang-tidy|STM32CubeIDE/Application/User/Core/dive_log.c|clang-analyzer-security.insecureAPI.DeprecatedOrUnsafeBufferHandling -->
- **Severity:** HIGH
- **Tool:** clang-tidy
- **Check:** `clang-analyzer-security.insecureAPI.DeprecatedOrUnsafeBufferHandling`
- **Location:** `STM32CubeIDE/Application/User/Core/dive_log.c:109`
- **Message:** Call to function 'memset' is insecure — replace with 'memset_s'
- **Justification:** False positive on embedded target. `memset_s` is not available in ARM newlib nano (`--specs=nano.specs`). `memset` with explicit size is the correct safe pattern on this platform. Buffer and size are compile-time paired.

---

## Suppressed 40

<!-- fingerprint: clang-tidy|STM32CubeIDE/Application/User/Core/ext_flash_storage.c|clang-analyzer-security.insecureAPI.DeprecatedOrUnsafeBufferHandling -->
- **Severity:** HIGH
- **Tool:** clang-tidy
- **Check:** `clang-analyzer-security.insecureAPI.DeprecatedOrUnsafeBufferHandling`
- **Location:** `STM32CubeIDE/Application/User/Core/ext_flash_storage.c:146`
- **Message:** Call to function 'memset' is insecure — replace with 'memset_s'
- **Justification:** Same as Suppressed 39 — `memset_s` unavailable in ARM newlib nano. Explicit size argument is the correct embedded pattern.

---

## Suppressed 41

<!-- fingerprint: clang-tidy|STM32CubeIDE/Application/User/Core/screens/screen_calibration.c|clang-analyzer-security.insecureAPI.DeprecatedOrUnsafeBufferHandling -->
- **Severity:** HIGH
- **Tool:** clang-tidy
- **Check:** `clang-analyzer-security.insecureAPI.DeprecatedOrUnsafeBufferHandling`
- **Location:** `STM32CubeIDE/Application/User/Core/screens/screen_calibration.c:518`
- **Message:** Call to function 'snprintf' is insecure — replace with 'snprintf_s'
- **Justification:** Same as Suppressed 6 — `snprintf_s` unavailable in ARM newlib nano. `snprintf` with explicit `sizeof(buf)` bound IS the safe pattern on this platform. Format strings are compile-time constants; no user input.

---

## Suppressed 42

<!-- fingerprint: clang-tidy|STM32CubeIDE/Application/User/Core/screens/screen_dive_log.c|clang-analyzer-security.insecureAPI.DeprecatedOrUnsafeBufferHandling -->
- **Severity:** HIGH
- **Tool:** clang-tidy
- **Check:** `clang-analyzer-security.insecureAPI.DeprecatedOrUnsafeBufferHandling`
- **Location:** `STM32CubeIDE/Application/User/Core/screens/screen_dive_log.c:133`
- **Message:** Call to function 'snprintf' is insecure — replace with 'snprintf_s'
- **Justification:** Same as Suppressed 6.

---

## Suppressed 43

<!-- fingerprint: clang-tidy|STM32CubeIDE/Application/User/Core/screens/screen_sensor_data.c|clang-analyzer-security.insecureAPI.DeprecatedOrUnsafeBufferHandling -->
- **Severity:** HIGH
- **Tool:** clang-tidy
- **Check:** `clang-analyzer-security.insecureAPI.DeprecatedOrUnsafeBufferHandling`
- **Location:** `STM32CubeIDE/Application/User/Core/screens/screen_sensor_data.c:114`
- **Message:** Call to function 'snprintf' is insecure — replace with 'snprintf_s'
- **Justification:** Same as Suppressed 6.

---

## Suppressed 44

<!-- fingerprint: clang-tidy|STM32CubeIDE/Application/User/Core/screens/screen_settings.c|clang-analyzer-security.insecureAPI.DeprecatedOrUnsafeBufferHandling -->
- **Severity:** HIGH
- **Tool:** clang-tidy
- **Check:** `clang-analyzer-security.insecureAPI.DeprecatedOrUnsafeBufferHandling`
- **Location:** `STM32CubeIDE/Application/User/Core/screens/screen_settings.c:95`
- **Message:** Call to function 'snprintf' is insecure — replace with 'snprintf_s'
- **Justification:** Same as Suppressed 6.

---

## Suppressed 45

<!-- fingerprint: clang-tidy|STM32CubeIDE/Application/User/Core/sensor_diagnostics.c|clang-analyzer-security.insecureAPI.DeprecatedOrUnsafeBufferHandling -->
- **Severity:** HIGH
- **Tool:** clang-tidy
- **Check:** `clang-analyzer-security.insecureAPI.DeprecatedOrUnsafeBufferHandling`
- **Location:** `STM32CubeIDE/Application/User/Core/sensor_diagnostics.c:192`
- **Message:** Call to function 'memset' is insecure — replace with 'memset_s'
- **Justification:** Same as Suppressed 39 — `memset_s` unavailable in ARM newlib nano.

---

## Suppressed 46

<!-- fingerprint: clang-tidy|STM32CubeIDE/Application/User/Core/w25q128.c|clang-analyzer-security.insecureAPI.DeprecatedOrUnsafeBufferHandling -->
- **Severity:** HIGH
- **Tool:** clang-tidy
- **Check:** `clang-analyzer-security.insecureAPI.DeprecatedOrUnsafeBufferHandling`
- **Location:** `STM32CubeIDE/Application/User/Core/w25q128.c:216`
- **Message:** Call to function 'memset' is insecure — replace with 'memset_s'
- **Justification:** Same as Suppressed 39 — `memset_s` unavailable in ARM newlib nano.

---

## Suppressed 47

<!-- fingerprint: flawfinder|STM32CubeIDE/Application/User/Core/dive_log.c:133|buffer -->
- **Severity:** MEDIUM
- **Tool:** flawfinder
- **Check:** `buffer`
- **Location:** `STM32CubeIDE/Application/User/Core/dive_log.c:133:5`
- **Message:** memcpy — does not check for buffer overflows (CWE-120)
- **Justification:** `memcpy(tmp, buf, DIVE_LOG_META_ENTRY_SIZE)` — `tmp` is declared `uint8_t tmp[DIVE_LOG_META_ENTRY_SIZE]` and `buf` is the same compile-time-sized parameter. No overflow possible.

---

## Suppressed 48

<!-- fingerprint: flawfinder|STM32CubeIDE/Application/User/Core/screens/screen_dive_log.c:125|buffer -->
- **Severity:** MEDIUM
- **Tool:** flawfinder
- **Check:** `buffer`
- **Location:** `STM32CubeIDE/Application/User/Core/screens/screen_dive_log.c:125:12`
- **Message:** char — statically-sized arrays can be improperly restricted (CWE-119/120)
- **Justification:** Same as Suppressed 30 — static `char` buffer used with `snprintf(buf, sizeof(buf), ...)`. No external input reaches without truncation.

---

## Suppressed 49

<!-- fingerprint: flawfinder|STM32CubeIDE/Application/User/Core/screens/screen_dive_log.c:158|buffer -->
- **Severity:** MEDIUM
- **Tool:** flawfinder
- **Check:** `buffer`
- **Location:** `STM32CubeIDE/Application/User/Core/screens/screen_dive_log.c:158:12`
- **Message:** char — statically-sized arrays can be improperly restricted (CWE-119/120)
- **Justification:** Same as Suppressed 30.

---

## Suppressed 50

<!-- fingerprint: flawfinder|STM32CubeIDE/Application/User/Core/screens/screen_dive_log.c:159|buffer -->
- **Severity:** MEDIUM
- **Tool:** flawfinder
- **Check:** `buffer`
- **Location:** `STM32CubeIDE/Application/User/Core/screens/screen_dive_log.c:159:12`
- **Message:** char — statically-sized arrays can be improperly restricted (CWE-119/120)
- **Justification:** Same as Suppressed 30.

---

## Suppressed 51

<!-- fingerprint: flawfinder|STM32CubeIDE/Application/User/Core/screens/screen_main.c:761|buffer -->
- **Severity:** MEDIUM
- **Tool:** flawfinder
- **Check:** `buffer`
- **Location:** `STM32CubeIDE/Application/User/Core/screens/screen_main.c:761:9`
- **Message:** char — statically-sized arrays can be improperly restricted (CWE-119/120)
- **Justification:** Same as Suppressed 30.

---

## Suppressed 52

<!-- fingerprint: flawfinder|STM32CubeIDE/Application/User/Core/screens/screen_main.c:780|buffer -->
- **Severity:** MEDIUM
- **Tool:** flawfinder
- **Check:** `buffer`
- **Location:** `STM32CubeIDE/Application/User/Core/screens/screen_main.c:780:9`
- **Message:** char — statically-sized arrays can be improperly restricted (CWE-119/120)
- **Justification:** Same as Suppressed 30.

---

## Suppressed 53

<!-- fingerprint: flawfinder|STM32CubeIDE/Application/User/Core/screens/screen_sensor_data.c:111|buffer -->
- **Severity:** MEDIUM
- **Tool:** flawfinder
- **Check:** `buffer`
- **Location:** `STM32CubeIDE/Application/User/Core/screens/screen_sensor_data.c:111:12`
- **Message:** char — statically-sized arrays can be improperly restricted (CWE-119/120)
- **Justification:** Same as Suppressed 30.

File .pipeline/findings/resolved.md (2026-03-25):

# Resolved Findings

## Resolution Batch — 2026-03-25

**Scope:** `dive_log.c` | **Severity floor:** MEDIUM (manual audit findings)

### Fixed

| # | Finding | File | Fix Applied |
|---|---|---|---|
| DL-1 | MEDIUM — deferred erase return ignored; `pending_erase_addr` cleared even on SPI failure | `dive_log.c:303` | Wrapped `w25q128_erase_sector` in `if (... == W25Q128_OK)` guard; failed erases now retry on the next 1 Hz surface tick |
| DL-2 | MEDIUM — `log_id++` and `dive_active = true` committed before confirming `entry_write` success | `dive_log.c:309–330` | Restructured dive-start block: snapshot PPO first, call `entry_write`, only update `log_id` / `dive_active` / `prev_*` inside the success branch |
| DL-3 | MEDIUM — `int32_t o2_s_ppo[i]` cast to `uint16_t` without negative guard; sensor fault producing negative PPO wraps to 65535 and causes runaway 1 Hz logging | `dive_log.c:358,317,373` | Added `raw > 0` guard at all three cast sites; negative PPO stores as 0 |
| DL-4 | MEDIUM — `depth_mm` (int32_t) divided and cast to `uint16_t` without upper-bound clamp; EMI bit-flip could produce unexpected depth value | `dive_log.c:297` | Added intermediate `uint32_t depth_mm_u` with clamp to `655350` (65535 cm × 10) before division |

---

## Resolution Batch — 2026-03-23

**Scope:** All modules | **Severity floor:** All (CRITICAL → LOW)

### Fixed

| # | Finding | File | Fix Applied |
|---|---|---|---|
| 1 | HIGH — uninitvar `t` (cppcheck) | `sensor.c:70` | Added `= {0}` to array declaration; prevents UB if `n == 0` at call site |
| 2 | HIGH — implicit widening of multiplication (clang-tidy) | `ext_flash_storage.c:511` | Added explicit cast `(uint32_t)(s * 4096U)` to make widening intent visible to static analysis on 64-bit host |
| 3 | HIGH — unused parameter `data` (clang-tidy) | `ms5837.c:280` | Added `(void)data;` at top of `ms5837_init()`; parameter retained for API symmetry |
| 4 | MEDIUM — unreadVariable `gamma_index` (cppcheck) | `main.c:656` | **Bug fix**: `backlight_gamma_lut[10]` was hardcoded — brightness setting was being silently ignored. Changed to `backlight_gamma_lut[gamma_index]` so LCD brightness now respects user setting |
| 5 | MEDIUM — redundantAssignment `P` (cppcheck) | `ms5837.c:212` | Removed the first (uncorrected) P calculation; P is now computed only once with corrected OFF/SENS after second-order temperature compensation |
| 6 | MEDIUM — variableScope `hal_status` (cppcheck) | `ms5837.c:74` | Moved `HAL_StatusTypeDef hal_status` declaration from function scope into the for-loop body where it is first assigned |
| 7 | MEDIUM — shadowVariable `sensor_data` (cppcheck) | `screen_sensor_data.c:110` | Removed redundant `extern volatile sensor_data_t sensor_data;` local declaration; `sensor.h` (already included) provides the file-scope extern |

### Suppressed (with justification)

| # | Finding | File | Justification |
|---|---|---|---|
| 8 | MEDIUM — constParam `htim` | `main.c:252` | HAL weak-symbol override — signature must match HAL exactly |
| 9 | MEDIUM — funcArgNamesDifferent `htim_base` | `hal_msp.c:802` | CubeMX-generated naming inconsistency |
| 10 | MEDIUM — constParam `hi2c` | `hal_msp.c:431` | CubeMX-generated HAL MSP hook |
| 11 | MEDIUM — knownConditionTrueFalse `next_seq==0U` | `ext_flash_storage.c:340` | Intentional UINT32_MAX wrap-around defensive guard |
| 12 | MEDIUM — knownConditionTrueFalse `num_sensors>3` | `screen_main.c:649` | Compile-time constant; dead code documents the 3-sensor constraint |
| 13 | MEDIUM — constVariable `param_madctl` | `st7789v.c:42` | HAL_SPI_Transmit requires non-const `uint8_t*` |
| 14 | MEDIUM — constParam `buf` | `w25q128.c:20` | HAL_SPI_Transmit requires non-const `uint8_t*` |
| 15 | MEDIUM — constVariable `tx` | `w25q128.c:111` | HAL_SPI_TransmitReceive requires non-const `uint8_t* pTxData` |
| 16–19 | MEDIUM — memcpy buffer (×4) | `ext_flash_storage.c:172,199,244,273` | Both src/dst are compile-time-sized buffers; sizes always match |
| 20–27 | MEDIUM — char array buffer (×8) | screen_calibration, screen_main, screen_sensor_data, screen_settings | All use `snprintf(buf, sizeof(buf), ...)` — writes bounded by declaration size |
| 28 | MEDIUM — complexity HAL_ADC_MspInit CC=17 | `hal_msp.c:115` | CubeMX-generated; not modifiable |

### Deferred (needs future refactoring task)

| # | Finding | File | Reason |
|---|---|---|---|
| 29 | MEDIUM — complexity `main` CC=23 | `main.c:547` | main() contains CubeMX init sections; refactoring USER CODE portions is a separate task |
| 30 | MEDIUM — `build_screen_content` length 228 lines | `screen_calibration.c:56` | Needs dedicated UI refactoring sprint |
| 31 | MEDIUM — `screen_calibration_update` CC=22 | `screen_calibration.c:513` | Needs dedicated UI refactoring sprint |
| 32 | MEDIUM — `screen_calibration_on_button` CC=21 | `screen_calibration.c:634` | Needs dedicated UI refactoring sprint |
| 33 | MEDIUM — `build_screen_content` length 309 lines | `screen_main.c:87` | Needs dedicated UI refactoring sprint |
| 34 | MEDIUM — `screen_main_update` CC=46 | `screen_main.c:519` | Highest priority refactor — CC=46 is the largest complexity risk in the codebase |
| 35 | MEDIUM — `ext_cal_iterate` CC=16 | `ext_flash_storage.c:535` | Borderline; can be addressed when ext_flash_storage is next touched |
| 36 | MEDIUM — `sensor_data_update` CC=23 | `sensor.c:182` | Borderline; can be addressed when sensor processing is next touched |

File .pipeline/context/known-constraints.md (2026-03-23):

# Known Constraints & Intentional Deviations

## Hardware Quirks — STM32G474CCTx
- 128 KB SRAM, 256 KB Flash (single-bank) — **DBANK=0 must be set in Options Bytes**;
  factory default DBANK=1 splits flash into two 128 KB banks and breaks the 256 KB linker script
- No external RAM — LVGL 20-line partial framebuffer (~15 KB) fits within internal 128 KB SRAM
- OPAMP1/OPAMP2/OPAMP3 used for 16× signal conditioning of three O2 sensor cells;
  outputs routed internally to ADC1/ADC2/ADC3 channels respectively
- Internal Vrefint (via ADC4) used for ADC calibration reference
- I2C1 has **no DMA stream configured** — MS5837 pressure sensor uses IT (interrupt) mode only;
  never call `HAL_I2C_Master_Receive_DMA()` on I2C1

## External Flash (W25Q128 via SPI1)
- All persistent data lives on the W25Q128, not internal flash
- Settings: ping-pong wear-levelling across sector 0 and sector 1 (4 KB each), 28-byte entries, CRC32
- Calibration: append-only log in sectors 2–17 (64 KB), 48-byte entries, up to 1280 records
- SPI1 is dedicated to the W25Q128; do not share it with other peripherals

## Intentional Patterns
- **CubeMX-generated code style**: HAL MSP, IT handler, and main.c init sections follow
  STM32CubeMX conventions with `USER CODE BEGIN/END` markers. Analysis should focus on
  USER CODE sections, not generated boilerplate. Never modify code outside USER CODE blocks.
- **LVGL memory management**: LVGL v8.3.11 uses its own heap allocator (`lv_mem`).
  Standard malloc/free warnings in LVGL code are expected and should be suppressed.
- **HAL library warnings**: Findings inside `Drivers/STM32G4xx_HAL_Driver/` are out of scope
  — we do not modify vendor code.
- **No HAL re-initialization in app code**: all peripherals are configured once by CubeMX-
  generated code; application code only calls `HAL_*_Start()` / runtime control functions.
- **Flash I/O uses uint64_t array packing** (not `__attribute__((packed))` structs) to avoid
  unaligned access faults on Cortex-M4.
- **LVGL screen lifecycle**: Create → Load → Delete (in that order) to prevent HardFault from
  deleting an active screen.
- **DMA flush completion**: `lv_disp_flush_ready()` is called in `HAL_SPI_TxCpltCallback()`,
  never inside the flush callback itself.

## Build Configuration
- Compiler: arm-none-eabi-gcc (GNU Tools for STM32, STM32CubeIDE 1.19.0)
- Standard: C11 (gnu11)
- Optimization: Debug `-O0`, Release `-Os` or `-O2`
- Linker script: `STM32G474CCTX_FLASH.ld` (256 KB single-bank)
- First build after adding new `.c` files **must** be done inside STM32CubeIDE (Project → Build All)
  to regenerate `subdir.mk` and `objects.list`; after that, command-line `make` works

## Known Limitations to Accept
- No hardware watchdog currently enabled (tracked as HIGH finding in safety audit)
- Fault handlers loop forever (no reset on hard fault) — intentional for debugger attachment
- No I2C bus recovery on lock-up (tracked as HIGH finding)

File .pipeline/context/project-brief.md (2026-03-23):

# Project Brief

## Device Purpose
Closed-circuit rebreather (CCR) PPO2 monitoring and display device with
vibrotactile alarm system. Reads oxygen partial pressure from three galvanic
oxygen sensors via ADC (OPAMP 16× gain), processes readings, displays on
a 320×240 SPI TFT screen, and triggers vibration motor alarms on
hypoxia/hyperoxia threshold violations. Also monitors dive depth via an
MS5837-30BA I2C pressure sensor and tracks long-term PPO2 drift trends.

**Device failure = diver may not receive hypoxia/hyperoxia warning = potential fatality.**

## Hardware
- **MCU**: STM32G474CCTx (Cortex-M4, 96 MHz, 256 KB Flash single-bank, 128 KB RAM)
- **Display**: 320×240 SPI TFT (ST7789V driver, SPI2 DMA)
- **O2 Sensors**: 3× galvanic cells via OPAMP1/2/3 (16× gain) → ADC1/2/3
- **Pressure Sensor**: MS5837-30BA (I2C1, interrupt-driven FSM)
- **Storage**: W25Q128 external SPI NOR flash (16 MB) for settings and calibration
- **Vibro Motor**: TIM5 CH1 PWM (PA0)
- **Buttons**: 2× EXTI (BTN_M=PA2, BTN_S=PA3)
- **Battery Monitor**: ADC4 channel (PB12), 3× voltage divider

## Safety Classification
Life-safety diving equipment. No formal SIL classification but designed
to SIL 2 equivalent principles. Single-fault tolerant for critical alarm path.

## Operating Environment
- Temperature range: 2°C to 40°C (water/ambient)
- Vibration/shock: Moderate (diving equipment handling, wave action)
- EMI exposure: Low (underwater, but potential from other dive electronics)
- Power supply: Battery powered (LiPo; full range characterised via battery monitor)
- Expected continuous runtime: 3-4 hours per dive
- Pressure: Device at surface pressure (not pressure-exposed)
- Moisture: High humidity environment, potential condensation

## Critical Functions (failure = safety hazard)
1. PPO2 reading acquisition and processing (ADC → OPAMP → calibrated value)
2. Alarm threshold comparison and vibrotactile alarm triggering (3-level FSM)
3. Display of current PPO2 values to diver
4. Sensor fault detection (open circuit, short circuit, degraded sensor)

## Important Functions (failure = device unusable but not dangerous)
1. User interface / button handling
2. Two-point sensor calibration routine
3. Display brightness/mode control (TIM2 CH3 PWM backlight)
4. Depth monitoring (MS5837-30BA pressure sensor)
5. PPO2 drift tracking (3-minute linear regression, 10 s samples)
6. Sensor diagnostic / sensitivity degradation detection
7. Settings and calibration persistence (W25Q128 external flash, wear-levelled)
8. Dive log display

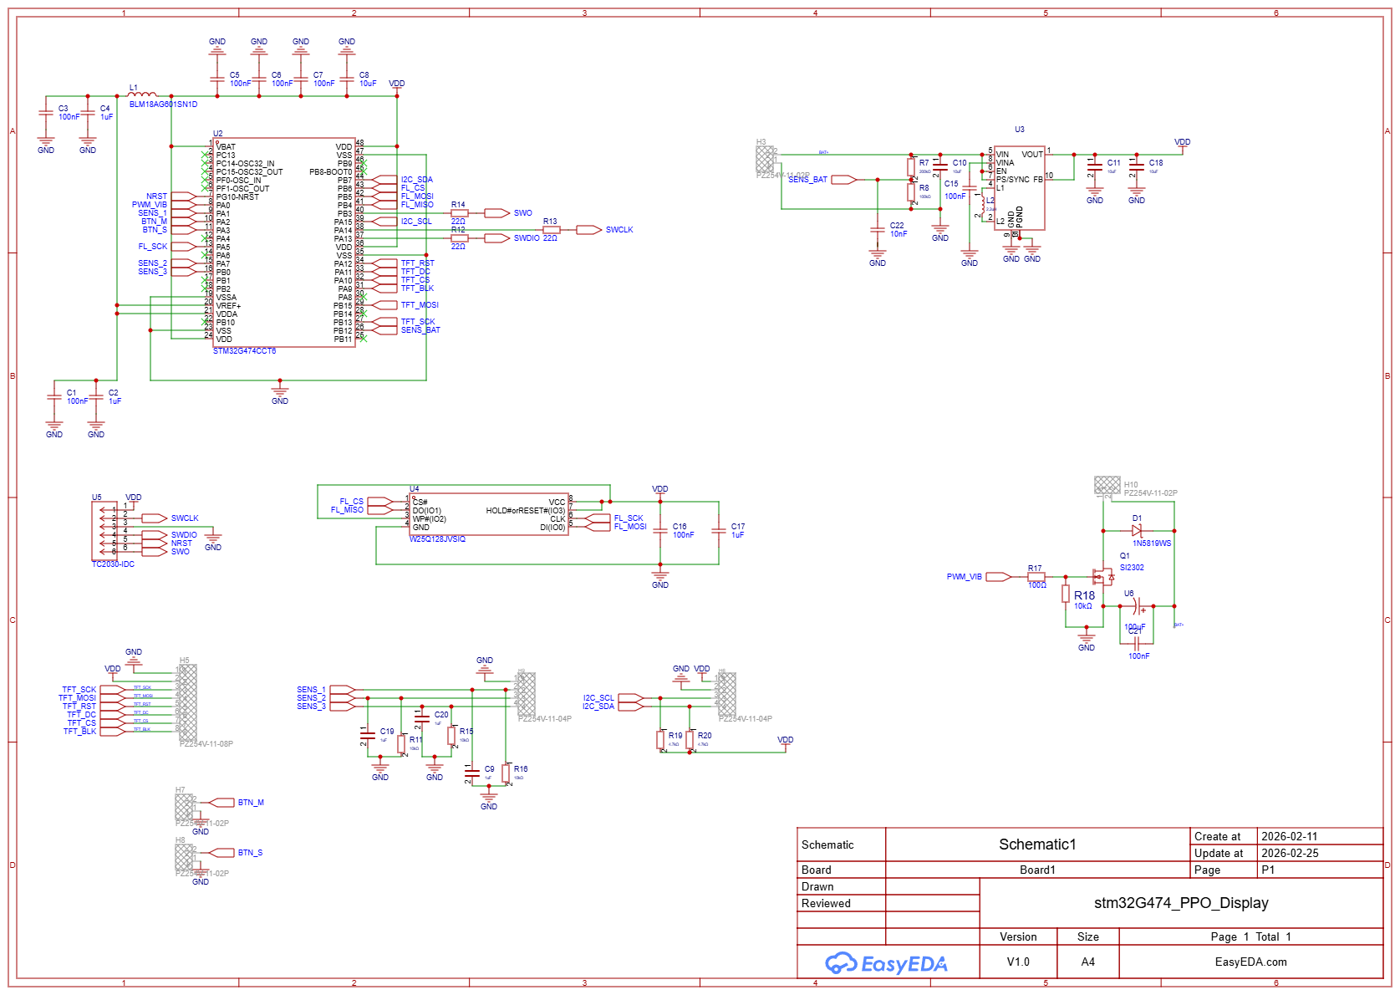
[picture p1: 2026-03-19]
SCH_Schematic1_1-P1_2026-02-25.png

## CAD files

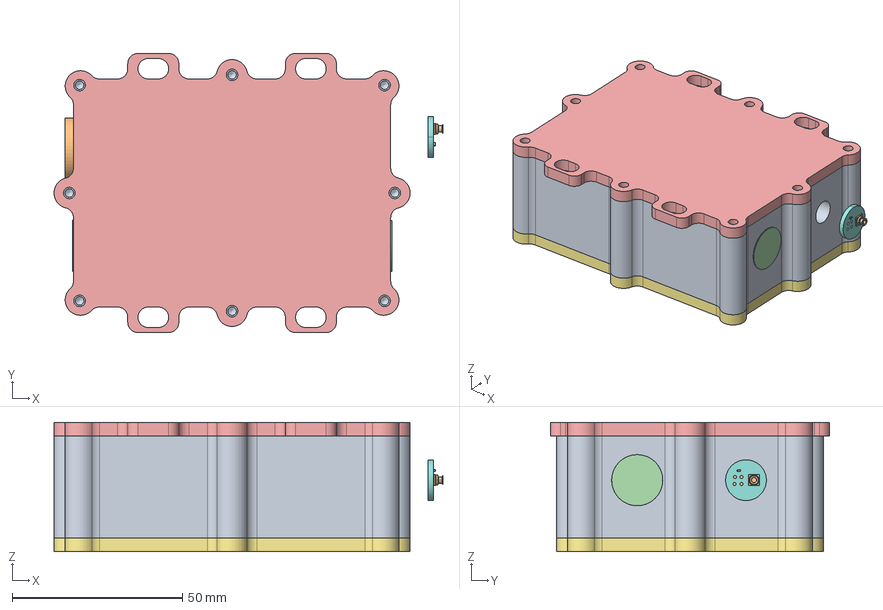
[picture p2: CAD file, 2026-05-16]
Housing/housing.FCStd
114.3 x 82.0 x 38.0 mm
Housing
Fischer
PCB
Button x 2
BackCover
C-CAT-BLPS0017
Window
Board~5dLw
C0402~C0402_L1.0-W0.5-H0.5~5dLw
SENSOR-SMD_4P-L3.3-W3.3-P2.00-BL~SENSOR-SMD_4P-L3.3-W3.3-P2.00-BL~5dLw

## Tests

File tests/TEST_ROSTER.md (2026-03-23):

# Test Roster — g474_port Unit Tests

## Overview

**Framework**: Custom native x86 GCC harness — no external dependencies
**Build**: `cd tests && make`
**Run**: `cd tests && make test`
**Compiler**: `gcc -Wall -Werror -Wextra -std=c11 -g -O0 -DUNIT_TEST -lm`

**Run command (Windows with WSL)**:
```
"C:/ST/STM32CubeIDE_1.19.0/STM32CubeIDE/plugins/com.st.stm32cube.ide.mcu.externaltools.make.win32_2.2.100.202601091506/tools/bin/make.exe" -C tests test
```
**Alternative**: From WSL terminal: `cd /mnt/g/stm/g474_port/tests && make test` (using system `make`)

---

## Test Files

| File | Module | Status | Test Count |
|---|---|---|---|
| test_calibration.c | calibration.c | READY | 9 |
| test_drift_tracker.c | drift_tracker.c | READY | 13 |
| test_flash_utils.c | flash_utils.c | READY | 22 |
| test_warning.c | warning.c | READY | 15 |
| test_settings.c | settings_storage.c | READY | 22 |
| test_pressure_sensor.c | pressure_sensor.c | READY | 7 |
| test_ms5837.c | ms5837.c | READY | 7 |

**Total tests: 95**

---

## Modules Excluded (HAL-Dependent)

| Module | Reason |
|---|---|
| sensor_diagnostics.c | `sensor_diagnostics_calculate()` calls `flash_calibration_iterate()` / `flash_calibration_get_count()` which iterate SPI flash via `ext_flash_storage`. No pure-logic path. |
| button.c | GPIO + EXTI interrupt-driven. All functions touch HAL_GPIO. |
| st7789v.c | SPI + DMA display driver. No pure logic. |
| w25q128.c | SPI NOR flash driver. Hardware-only. |
| ext_flash_storage.c | W25Q128 SPI operations (sector erase, page program). |
| flash_storage.c | Internal STM32 flash (HAL_FLASH_Program). |
| screen_*.c | LVGL + HAL-dependent. |
| screen_manager.c | LVGL screen switching. |

---

## Functions Under Test

### calibration.c

- [x] `calibrate_sensor`: normal two-point calibration → coefficients written
- [x] `calibrate_sensor`: division by zero (identical raw readings) → NON_CALIBRATED
- [x] `calibrate_sensor`: inverted slope (ppo up, raw down) → NON_CALIBRATED
- [x] `calibrate_sensor`: dead sensor (zero ppo delta) → NON_CALIBRATED
- [x] `calibrate_sensor`: separation +49 counts → NON_CALIBRATED (< 50 minimum)
- [x] `calibrate_sensor`: separation -49 counts → NON_CALIBRATED
- [x] `calibrate_sensor`: exactly 50 count separation → succeeds
- [x] `calibrate_sensor`: calibration points stored in s_cpt[]
- [x] `calibrate_sensor`: coefficients mathematically correct for known linear relation

### drift_tracker.c

- [x] `drift_tracker_init`: all fields zeroed
- [x] `drift_tracker_sample`: 1 sample → count=1, slope=0 (below minimum)
- [x] `drift_tracker_sample`: 2 samples → count=2, slope=0
- [x] `drift_tracker_sample`: 3 flat samples → slope=0
- [x] `drift_tracker_sample`: 3 rising samples → positive slope (+36 mbar/min)
- [x] `drift_tracker_sample`: 3 falling samples → negative slope (-36 mbar/min)
- [x] `drift_tracker_sample`: >18 samples → count saturates at DRIFT_WINDOW_SIZE
- [x] `drift_tracker_sample`: circular buffer wraps correctly after full window
- [x] `drift_get_rate_per_min`: returns stored drift_rate_mbar_per_min
- [x] `drift_tracker_calculate_slope`: corrupted sample_count > window → safe reset
- [x] `drift_tracker_calculate_slope`: constant +1/interval rate → 6 mbar/min output
- [x] `drift_tracker_calculate_slope`: count < 3 → returns 0
- [x] Multiple independent tracker structs do not interfere

### flash_utils.c (pure math only)

**HAL-excluded**: `flash_unlock`, `flash_lock`, `flash_clear_errors`, `flash_page_erase`

- [x] `flash_crc16_ccitt`: "123456789" → 0x29B1 (standard vector)
- [x] `flash_crc16_ccitt`: empty buffer → 0xFFFF (initial seed)
- [x] `flash_crc16_ccitt`: single zero byte → differs from seed
- [x] `flash_crc16_ccitt`: different data → different CRC
- [x] `flash_crc16_ccitt`: same data → same CRC (deterministic)
- [x] `flash_crc32`: "123456789" → 0xCBF43926 (standard vector)
- [x] `flash_crc32`: empty buffer → 0x00000000
- [x] `flash_crc32`: single byte → non-zero
- [x] `flash_crc32`: different data → different CRC
- [x] `flash_crc32`: all-zeros 8 bytes → deterministic
- [x] `flash_make_dword`: basic pack (0x12345678, 0xABCDEF01) → 0xABCDEF0112345678
- [x] `flash_make_dword`: zero both → 0
- [x] `flash_make_dword`: max values → 0xFFFFFFFFFFFFFFFF
- [x] `flash_get_low_word`: extracts lower 32 bits
- [x] `flash_get_high_word`: extracts upper 32 bits
- [x] Round-trip: pack then unpack recovers original low/high words
- [x] `flash_float_to_u32`: 0.0f → 0x00000000
- [x] `flash_float_to_u32`: 1.0f → 0x3F800000 (IEEE 754)
- [x] `flash_float_to_u32`: 0.42f round-trip → bit-for-bit identical
- [x] `flash_u32_to_float`: 0x3F800000 → 1.0f
- [x] Float round-trip: negative value preserved
- [x] Float round-trip: large value preserved

### warning.c

**HAL-excluded**: `warning_apply_style` (LVGL), `vibro_tick_5ms` (TIM PWM), `vibro_hw_start/stop`

- [x] `warning_check_sensor`: invalid sensor index → WARNING_NONE
- [x] `warning_check_sensor`: s_valid[i] == false → WARNING_NONE
- [x] `warning_check_sensor`: PPO in safe zone (700 mbar) → WARNING_NONE
- [x] `warning_check_sensor`: PPO below min (159 < 160) → WARNING_CRITICAL
- [x] `warning_check_sensor`: PPO above max (1401 > 1400) → WARNING_CRITICAL
- [x] `warning_check_sensor`: PPO exactly at min (160) → NOT critical (strict <)
- [x] `warning_check_sensor`: PPO exactly at max (1400) → NOT critical (strict >)
- [x] `warning_check_sensor`: PPO near min (220) → WARNING_NEAR_CRITICAL
- [x] `warning_check_sensor`: PPO near max (1350) → WARNING_NEAR_CRITICAL
- [x] `warning_check_sensor`: PPO 110 above setpoint (810) → WARNING_YELLOW_DRIFT
- [x] `warning_check_sensor`: PPO 110 below setpoint (590) → WARNING_YELLOW_DRIFT
- [x] `warning_check_sensor`: PPO exactly at setpoint (700) → WARNING_NONE
- [x] `warning_check_sensor`: PPO 90 from setpoint (790) → WARNING_NONE (< 100)
- [x] `warning_check_sensor`: active_setpoint=2 → uses ppo_setpoint2
- [x] `warning_check_sensor`: priority — CRITICAL beats NEAR_CRITICAL

### settings_storage.c (pure logic only)

**HAL-excluded**: `settings_save`, `settings_load`, `settings_erase` (delegate to ext_flash_storage)

- [x] `settings_init_defaults`: lcd_brightness = BRIGHTNESS_DEFAULT (100)
- [x] `settings_init_defaults`: min_ppo_threshold = MIN_PPO_DEFAULT (160)
- [x] `settings_init_defaults`: max_ppo_threshold = MAX_PPO_DEFAULT (1400)
- [x] `settings_init_defaults`: delta_ppo_threshold = DELTA_PPO_DEFAULT (100)
- [x] `settings_init_defaults`: warning_ppo_threshold = WARNING_PPO_DEFAULT (100)
- [x] `settings_init_defaults`: ppo_setpoint1/2 = 700/1100
- [x] `settings_validate`: in-range defaults → unchanged
- [x] `settings_validate`: brightness below BRIGHTNESS_MIN → clamped to min
- [x] `settings_validate`: brightness above BRIGHTNESS_MAX → clamped to max
- [x] `settings_validate`: brightness at BRIGHTNESS_MIN → unchanged
- [x] `settings_validate`: min_ppo below MIN_PPO_MIN → clamped
- [x] `settings_validate`: min_ppo above MIN_PPO_MAX → clamped
- [x] `settings_validate`: max_ppo below MAX_PPO_MIN → clamped
- [x] `settings_validate`: max_ppo above MAX_PPO_MAX → clamped
- [x] `settings_validate`: delta_ppo below DELTA_PPO_MIN → clamped
- [x] `settings_validate`: delta_ppo above DELTA_PPO_MAX → clamped
- [x] `settings_validate`: warning_ppo below WARNING_PPO_MIN → clamped
- [x] `settings_validate`: warning_ppo above WARNING_PPO_MAX → clamped
- [x] `settings_validate`: setpoint1 below SETPOINT1_MIN → clamped
- [x] `settings_validate`: setpoint1 above SETPOINT1_MAX → clamped
- [x] `settings_validate`: setpoint2 below SETPOINT2_MIN → clamped
- [x] `settings_validate`: setpoint2 above SETPOINT2_MAX → clamped

### pressure_sensor.c

- [x] `pressure_sensor_calculate_depth_mm`: same pressure → 0 mm depth
- [x] `pressure_sensor_calculate_depth_mm`: 10m depth equivalent → -9950 mm
- [x] `pressure_sensor_calculate_depth_mm`: pressure below surface → positive mm
- [x] `pressure_sensor_calculate_depth_mm`: exact coefficient (10000 delta → 995 mm)
- [x] `pressure_sensor_calculate_depth_mm`: large positive delta
- [x] `pressure_sensor_calculate_depth_mm`: large negative delta (symmetric)
- [x] `pressure_sensor_init`: populates sensor_data.pressure with correct defaults

### ms5837.c (ms5837_calculate only)

**HAL-excluded**: `ms5837_reset`, `ms5837_read_prom`, `ms5837_read_adc`,
`ms5837_convert_d1/d2`, `ms5837_init`, `ms5837_read_pt`

- [x] `ms5837_calculate`: returns MS5837_OK for valid inputs
- [x] `ms5837_calculate`: stores D1_raw and D2_raw in data struct
- [x] `ms5837_calculate`: pressure_mbar in plausible range (0–35000)
- [x] `ms5837_calculate`: temperature_c100 in plausible range (-2000–8500)
- [x] `ms5837_calculate`: low-temperature path (TEMP < 2000) → compensation applied
- [x] `ms5837_calculate`: high-temperature path (TEMP >= 2000) → compensation applied
- [x] `ms5837_calculate`: all-zero coefficients → no crash, returns OK

---

## Mock Files

| File | Purpose |
|---|---|
| `mocks/mock_stm32.h` | HAL type stubs (TIM, I2C, SPI handles; IRQ macros; LL ADC macros) |
| `mocks/stm32g4xx_hal.h` | Forwarding stub → redirects `#include "stm32g4xx_hal.h"` to mock_stm32.h |
| `mocks/stm32g4xx_ll_adc.h` | LL ADC stub → redirects to mock_stm32.h |
| `mocks/lvgl.h` | Minimal LVGL type stubs (lv_obj_t, lv_color_t, style setters) |
| `mocks/main.h` | main.h stub → provides htim5 extern via mock_stm32.h |
| `mocks/screen_manager.h` | screen_manager_startup_complete() no-op stub |
| `mocks/ext_flash_storage.h` | ext_settings_save/load/erase stubs (inline, no-op) |
| `mocks/flash_storage.h` | flash_calibration_get_count/iterate stubs (return 0) |
| `mocks/mock_sensor_data.h` | Declares reset_sensor_data() and htim5 |
| `mocks/mock_sensor_data.c` | Defines sensor_data, active_setpoint, htim5; implements reset_sensor_data() |

---

## Known Limitations

1. **sensor_diagnostics_calculate()** cannot be tested without a real flash log.
   The static helpers (`calculate_mean`, `calculate_stddev`, `calc_sensitivity_ratio`,
   etc.) are `static` and not accessible from outside the TU.
   Workaround: expose them via `#ifdef UNIT_TEST` blocks if needed in future.

2. **sensor.c filter functions** (`filter_step_sensor`, `median_int32`,
   `mad_int32_q0`, `filter_step_sensor_two_stage`) are `static inline` or
   `static` and depend on module-level static state. They are compiled into the
   test binary but not directly exercised in this suite iteration.

3. **warning vibro state machine** (`warning_trigger_vibration`, `vibro_tick_5ms`,
   `vibro_acknowledge`, `vibro_is_active`) is compiled in with HAL TIM stubs.
   Behavioral timing tests (motor on/off sequencing) require either precise timing
   or a deeper mock of `vibro_hw_start/stop` — deferred.

---

## Changelog

| Date | Change |
|---|---|
| 2026-03-22 | Initial test suite created — 95 tests across 7 modules, all passing |

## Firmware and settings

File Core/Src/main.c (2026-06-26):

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
/* Includes ------------------------------------------------------------------*/
#include "main.h"

/* USER CODE BEGIN Includes */
#include <stdatomic.h>
#include <stdbool.h>
#include "stm32g4xx_ll_adc.h"
#include "stm32g4xx.h"
#include "sensor.h"
#include "lvgl.h"
#include "st7789v.h"
#include "screen_manager.h"
#include "button.h"
#include "flash_storage.h"
#include "settings_storage.h"
#include "ext_flash_storage.h"
#include "drift_tracker.h"
#include "ms5837.h"
#include "w25q128.h"
#include "warning.h"
#include "dive_log.h"

/* USER CODE END Includes */

/* USER CODE BEGIN PTD */




// Display configuration (landscape orientation)
#define LCD_H_RES       320
#define LCD_V_RES       240
#define DISP_BUF_LINES  20  // Number of lines in partial refresh buffer

// LVGL display buffer - single buffer for partial refresh mode
// RGB565 = 2 bytes per pixel, 10 lines = 320 * 10 * 2 = 6400 bytes
static lv_color_t disp_buf1[LCD_H_RES * DISP_BUF_LINES] = {0};
static lv_color_t disp_buf2[LCD_H_RES * DISP_BUF_LINES] = {0};

// LVGL v8 display driver structures (must be global for ISR access from other files)
static lv_disp_draw_buf_t disp_draw_buf;
lv_disp_drv_t disp_drv;  // Non-static so ISR can access it

static volatile uint16_t ADC1_VAL[1];   // SENSOR1 via VOPAMP1
static volatile uint16_t ADC2_VAL[1];   // SENSOR2 via VOPAMP2
static volatile uint16_t ADC3_VAL[1];   // SENSOR3 via VOPAMP3
static volatile uint16_t ADC4_VAL[2];   // [0]=VREFINT  [1]=BAT (PB12)
static volatile atomic_bool g_adc1_new = false;
static volatile atomic_bool g_adc2_new = false;
static volatile atomic_bool g_adc3_new = false;
static volatile atomic_bool g_adc4_new = false;

// Elapsed time counter (seconds since boot)
uint32_t g_elapsed_time_sec = 0;
/* Bottom timer start depth in mm. 1000 mm = 1 m. Change for bench testing. */
#define BOTTOM_TIMER_START_DEPTH_MM  1000


static volatile uint32_t g_ms = 0; // ms since boot (from 1kHz tick)
static bool g_debugger_connected = false; // cached once at boot; DHCSR doesn't change at runtime

static volatile atomic_bool g_flag_1hz = false;
static volatile atomic_bool g_flag_5ms = false;
static volatile atomic_bool g_flag_20ms = false;
static volatile atomic_bool g_flag_10s = false;  // NEW: 10-second flag for drift tracking


/**
 * Gamma 2.2 Lookup Table for Backlight PWM
 * Clock: 48 MHz | Prescaler: 0 | ARR: 4799 (10 kHz PWM)
 * Index 0 = OFF, Index 1 = 10% ... Index 10 = 100%
 * Provides perceptually linear brightness control
 */
const uint16_t backlight_gamma_lut[11] = {
      0,   // 0%   (OFF)
     30,   // 10%
    139,   // 20%
    339,   // 30%
    639,   // 40%
   1044,   // 50%
   1561,   // 60%
   2190,   // 70%
   2937,   // 80%
   3808,   // 90%
   4799    // 100% (MAX)
};

uint32_t vref_effective_mv = 3300;     // == VDDA in mV

// Debug: Store VREFINT raw reading for troubleshooting
uint16_t vrefint_raw_debug = 0;

// MS5837 pressure sensor calibration and data
static ms5837_calib_t ms5837_calib;  // Factory calibration coefficients
static ms5837_data_t ms5837_data;    // Latest pressure/temperature measurement
static volatile bool ms5837_initialized = false;  // Initialization status flag
static bool ms5837_surface_set = false;           // True after first reading captures actual ambient

/* MS5837 DMA-driven measurement FSM */
typedef enum {
    MS5837_FSM_IDLE = 0,
    MS5837_FSM_D2_CONV_TX,   /* D2 conversion command TX in progress */
    MS5837_FSM_WAIT_D2,
    MS5837_FSM_D2_READ_TX,
    MS5837_FSM_D2_READ_RX,
    MS5837_FSM_D1_CMD_TX,
    MS5837_FSM_WAIT_D1,
    MS5837_FSM_D1_READ_TX,
    MS5837_FSM_D1_READ_RX,
    MS5837_FSM_CALCULATE,
} ms5837_fsm_t;

static volatile ms5837_fsm_t  ms5837_fsm        = MS5837_FSM_IDLE;
static volatile uint32_t      ms5837_conv_start = 0;
static volatile uint32_t      ms5837_raw_D1     = 0;
static volatile uint32_t      ms5837_raw_D2     = 0;
static volatile uint32_t      ms5837_last_meas  = 0;
/* Static buffers required: DMA accesses them after function returns */
static uint8_t       ms5837_tx_buf[1]  = {0};
static uint8_t       ms5837_rx_buf[3]  = {0, 0, 0};

/* USER CODE END PTD */

ADC_HandleTypeDef hadc1;
ADC_HandleTypeDef hadc2;
ADC_HandleTypeDef hadc3;
ADC_HandleTypeDef hadc4;
DMA_HandleTypeDef hdma_adc1;
DMA_HandleTypeDef hdma_adc2;
DMA_HandleTypeDef hdma_adc3;
DMA_HandleTypeDef hdma_adc4;

I2C_HandleTypeDef hi2c1;

IWDG_HandleTypeDef hiwdg;

OPAMP_HandleTypeDef hopamp1;
OPAMP_HandleTypeDef hopamp2;
OPAMP_HandleTypeDef hopamp3;

SPI_HandleTypeDef hspi1;
SPI_HandleTypeDef hspi2;
DMA_HandleTypeDef hdma_spi2_tx;

TIM_HandleTypeDef htim1;
TIM_HandleTypeDef htim2;
TIM_HandleTypeDef htim3;
TIM_HandleTypeDef htim5;
TIM_HandleTypeDef htim6;

void SystemClock_Config(void);
static void MX_GPIO_Init(void);
static void MX_DMA_Init(void);
static void MX_ADC1_Init(void);
static void MX_ADC2_Init(void);
static void MX_ADC3_Init(void);
static void MX_ADC4_Init(void);
static void MX_I2C1_Init(void);
static void MX_OPAMP1_Init(void);
static void MX_OPAMP2_Init(void);
static void MX_OPAMP3_Init(void);
static void MX_SPI1_Init(void);
static void MX_SPI2_Init(void);
static void MX_TIM2_Init(void);
static void MX_TIM5_Init(void);
static void MX_TIM1_Init(void);
static void MX_TIM6_Init(void);
static void MX_TIM3_Init(void);
static void MX_IWDG_Init(void);
/* USER CODE BEGIN PFP */
void vibro_motor_test(void);

static void scheduler_tick_1kHz(void);
static void scheduler_tick_5ms(void);
static void scheduler_tick_20ms(void);
static void scheduler_tick_10s(void);

void system_shutdown(void);  // Power management


static bool emulate_profile = false;
static bool emulate_descend = true;
static int8_t emulate_depth = 0;

/* USER CODE END PFP */

/* USER CODE BEGIN 0 */


uint8_t isDebuggerConnected(void) {
    if (CoreDebug->DHCSR & CoreDebug_DHCSR_C_DEBUGEN_Msk) {
        return 1; // Debugger is attached
    }
    return 0; // Running standalone
}


void HAL_TIM_PeriodElapsedCallback(TIM_HandleTypeDef *htim) {
	if (htim->Instance == TIM6) {
		scheduler_tick_1kHz();
		scheduler_tick_5ms();
		scheduler_tick_20ms();
		scheduler_tick_10s();  // NEW: 10-second scheduler for drift tracking
	}
}


static void scheduler_tick_5ms(void){
		static uint32_t t1 = 0;
		if ((g_ms - t1) >= 5) {
			t1 = g_ms;
			atomic_store(&g_flag_5ms, true);
		}
}

static void scheduler_tick_20ms(void) {
	static uint32_t t = 0;
	if ((g_ms - t) >= 20) {
		t = g_ms;
		atomic_store(&g_flag_20ms, true);
	}
}

static void scheduler_tick_1kHz(void) {
	g_ms++;

	// 1 Hz: every 1000 ms
	static uint32_t t1 = 0;
	if ((g_ms - t1) >= 1000) {
		t1 = g_ms;
		atomic_store(&g_flag_1hz, true);
	}
}

static void scheduler_tick_10s(void) {
	static uint32_t t = 0;
	if ((g_ms - t) >= 10000) {  // 10 seconds = 10000 ms
		t = g_ms;
		atomic_store(&g_flag_10s, true);
	}
}

void HAL_ADC_ConvCpltCallback(ADC_HandleTypeDef *hadc) {
    if (hadc->Instance == ADC1) atomic_store(&g_adc1_new, true);
    if (hadc->Instance == ADC2) atomic_store(&g_adc2_new, true);
    if (hadc->Instance == ADC3) atomic_store(&g_adc3_new, true);
    if (hadc->Instance == ADC4) atomic_store(&g_adc4_new, true);
}

void HAL_SPI_TxCpltCallback(SPI_HandleTypeDef *hspi)
{
    if (hspi->Instance == SPI2) {
    //    HAL_GPIO_WritePin(LCD_CS_GPIO_Port, LCD_CS_Pin, GPIO_PIN_SET);
     //   my_disp_bus_busy = 0;

        // v8 API: pass driver struct pointer
        lv_disp_flush_ready(&disp_drv);
    }
}

/**
 * @brief System shutdown - Stop peripherals and enter Stop1 mode
 * @note Wakes on PA2 (BTN_M) via EXTI2 (already enabled by MX_GPIO_Init).
 *       GPIO state is retained in Stop1. On wake: full system reset for clean boot.
 *       IWDG continues in Stop1 — refreshed here to give the full ~6s window.
 *       Set option byte IWDG_STOP=0 in CubeProgrammer to freeze IWDG in Stop mode.
 */
void system_shutdown(void) {
    // Step 1: Put display to sleep via SPI (must happen before peripherals stop)
    // DISPOFF turns off panel output; SLPIN enters sleep (screen goes dark).
    // GPIO state is retained in Stop1 so CS/RST held here remain valid.
    ST7789V_SendCmd(ST7789_DISPOFF, NULL, 0);
    HAL_Delay(20);
    ST7789V_SendCmd(ST7789_SLPIN, NULL, 0);
    HAL_Delay(120);  // Required post-SLPIN settling per ST7789V datasheet
    HAL_GPIO_WritePin(TFT_CS_GPIO_Port,  TFT_CS_Pin,  GPIO_PIN_SET);   // Deselect
    HAL_GPIO_WritePin(TFT_RST_GPIO_Port, TFT_RST_Pin, GPIO_PIN_SET);   // Not in reset

    // Step 2: Turn off LCD backlight (TIM2_CH3 on TFT_BLK/PA9)
    HAL_TIM_PWM_Stop(&htim2, TIM_CHANNEL_3);
    __HAL_TIM_SET_COMPARE(&htim2, TIM_CHANNEL_3, 0);
    GPIO_InitTypeDef GPIO_InitStruct = {0};
    GPIO_InitStruct.Pin   = TFT_BLK_Pin;
    GPIO_InitStruct.Mode  = GPIO_MODE_OUTPUT_PP;
    GPIO_InitStruct.Pull  = GPIO_NOPULL;
    GPIO_InitStruct.Speed = GPIO_SPEED_FREQ_LOW;
    HAL_GPIO_Init(TFT_BLK_GPIO_Port, &GPIO_InitStruct);
    HAL_GPIO_WritePin(TFT_BLK_GPIO_Port, TFT_BLK_Pin, GPIO_PIN_RESET);

    // Step 3: Stop all peripherals
    HAL_ADC_Stop_DMA(&hadc1);
    HAL_ADC_Stop_DMA(&hadc2);
    HAL_ADC_Stop_DMA(&hadc3);
    HAL_ADC_Stop_DMA(&hadc4);
    HAL_TIM_Base_Stop_IT(&htim6);  // 1kHz scheduler
    HAL_TIM_Base_Stop(&htim3);     // ADC2 trigger
    HAL_OPAMP_Stop(&hopamp1);
    HAL_OPAMP_Stop(&hopamp2);
    HAL_OPAMP_Stop(&hopamp3);

    // Step 4: Clear pending BTN_M (PA2/EXTI2) flag — EXTI2_IRQn already enabled
    __HAL_PWR_CLEAR_FLAG(PWR_FLAG_WU);
    __HAL_GPIO_EXTI_CLEAR_IT(BTN_M_Pin);

    // Step 5: Enter Stop1 mode (~2 µA)
    // Refresh IWDG for full ~6s window (freeze with IWDG_STOP=0 option byte for indefinite sleep)
    HAL_IWDG_Refresh(&hiwdg);
    HAL_SuspendTick();
    HAL_PWREx_EnterSTOP1Mode(PWR_STOPENTRY_WFI);

    // Step 6: Wake-up — restore clocks and do a clean reset
    SystemClock_Config();
    HAL_ResumeTick();
    NVIC_SystemReset();
}

/**
 * @brief MS5837 main-loop tick — handles timer-wait states and CALCULATE.
 * All other state transitions happen inside DMA callbacks (ISR context).
 */
static void ms5837_fsm_tick(void)
{
    if (!ms5837_initialized) return;

    switch (ms5837_fsm) {

        case MS5837_FSM_IDLE:
            if ((g_ms - ms5837_last_meas) >= 1000U) {
                ms5837_tx_buf[0] = MS5837_CMD_CONV_D2 + MS5837_OSR_4096;
                if (HAL_I2C_Master_Transmit_IT(&hi2c1,
                        (uint16_t)(MS5837_I2C_ADDR << 1),
                        ms5837_tx_buf, 1U) == HAL_OK) {
                    ms5837_fsm = MS5837_FSM_D2_CONV_TX;  /* TxCplt advances to WAIT_D2 */
                } else {
                    ms5837_last_meas = g_ms;  /* back-off 1 s on bus error */
                }
            }
            break;

        case MS5837_FSM_WAIT_D2:
            if ((g_ms - ms5837_conv_start) >= MS5837_CONV_DELAY_4096) {
                ms5837_tx_buf[0] = MS5837_CMD_ADC_READ;
                if (HAL_I2C_Master_Transmit_IT(&hi2c1,
                        (uint16_t)(MS5837_I2C_ADDR << 1),
                        ms5837_tx_buf, 1U) == HAL_OK) {
                    ms5837_fsm = MS5837_FSM_D2_READ_TX;
                }
            }
            break;

        case MS5837_FSM_WAIT_D1:
            if ((g_ms - ms5837_conv_start) >= MS5837_CONV_DELAY_4096) {
                ms5837_tx_buf[0] = MS5837_CMD_ADC_READ;
                if (HAL_I2C_Master_Transmit_IT(&hi2c1,
                        (uint16_t)(MS5837_I2C_ADDR << 1),
                        ms5837_tx_buf, 1U) == HAL_OK) {
                    ms5837_fsm = MS5837_FSM_D1_READ_TX;
                }
            }
            break;

        case MS5837_FSM_CALCULATE:
            ms5837_calculate(&ms5837_calib, ms5837_raw_D1, ms5837_raw_D2, &ms5837_data);
            {
                int32_t scaled_p = ms5837_data.pressure_mbar * 20;
                /* Four pressure fields written from main-loop context only.
                 * If any field is ever read from ISR, wrap in __disable_irq()/__enable_irq(). */
                sensor_data.pressure.pressure_mbar = scaled_p;
                if (!ms5837_surface_set) {
                    /* Use actual ambient only if plausible surface pressure.
                     * 108300 Pa = 1083 mbar, highest sea-level pressure ever recorded.
                     * Anything above means device restarted underwater — keep sea-level default. */
                    if (scaled_p <= 108300) {
                        sensor_data.pressure.surface_pressure_mbar = scaled_p;
                    }
                    ms5837_surface_set = true;
                }
                sensor_data.pressure.temperature_c =
                    (int16_t)(ms5837_data.temperature_c100 / 100);
                sensor_data.pressure.depth_mm = (!emulate_profile)?
                    pressure_sensor_calculate_depth_mm(
                        scaled_p, sensor_data.pressure.surface_pressure_mbar):emulate_depth*1000;
                sensor_data.pressure.pressure_valid = true;
            }
            ms5837_last_meas = g_ms;
            ms5837_fsm = MS5837_FSM_IDLE;
            break;

        default:
            break;  /* TX/RX states: DMA in progress, nothing to do */
    }
}

void HAL_I2C_MasterTxCpltCallback(I2C_HandleTypeDef *hi2c)
{
    if (hi2c->Instance != I2C1) return;

    switch (ms5837_fsm) {
        case MS5837_FSM_D2_CONV_TX:
            /* D2 conversion command sent — start conversion timer */
            ms5837_conv_start = g_ms;
            ms5837_fsm = MS5837_FSM_WAIT_D2;
            break;

        case MS5837_FSM_D2_READ_TX:
            /* ADC read command for D2 sent — start 3-byte IT RX */
            if (HAL_I2C_Master_Receive_IT(hi2c,
                    (uint16_t)(MS5837_I2C_ADDR << 1), ms5837_rx_buf, 3U) == HAL_OK) {
                ms5837_fsm = MS5837_FSM_D2_READ_RX;
            } else {
                ms5837_fsm = MS5837_FSM_IDLE;
                ms5837_last_meas = g_ms;
            }
            break;

        case MS5837_FSM_D1_CMD_TX:
            /* D1 conversion command sent — start conversion timer */
            ms5837_conv_start = g_ms;
            ms5837_fsm = MS5837_FSM_WAIT_D1;
            break;

        case MS5837_FSM_D1_READ_TX:
            /* ADC read command for D1 sent — start 3-byte IT RX */
            if (HAL_I2C_Master_Receive_IT(hi2c,
                    (uint16_t)(MS5837_I2C_ADDR << 1), ms5837_rx_buf, 3U) == HAL_OK) {
                ms5837_fsm = MS5837_FSM_D1_READ_RX;
            } else {
                ms5837_fsm = MS5837_FSM_IDLE;
                ms5837_last_meas = g_ms;
            }
            break;

        default:
            break;
    }
}

void HAL_I2C_MasterRxCpltCallback(I2C_HandleTypeDef *hi2c)
{
    if (hi2c->Instance != I2C1) return;

    switch (ms5837_fsm) {
        case MS5837_FSM_D2_READ_RX:
            /* Save D2 raw ADC value */
            ms5837_raw_D2 = ((uint32_t)ms5837_rx_buf[0] << 16)
                          | ((uint32_t)ms5837_rx_buf[1] << 8)
                          |  (uint32_t)ms5837_rx_buf[2];
            /* Start D1 conversion command */
            ms5837_tx_buf[0] = MS5837_CMD_CONV_D1 + MS5837_OSR_4096;
            if (HAL_I2C_Master_Transmit_IT(hi2c,
                    (uint16_t)(MS5837_I2C_ADDR << 1),
                    ms5837_tx_buf, 1U) == HAL_OK) {
                ms5837_fsm = MS5837_FSM_D1_CMD_TX;
            } else {
                ms5837_fsm = MS5837_FSM_IDLE;
                ms5837_last_meas = g_ms;
            }
            break;

        case MS5837_FSM_D1_READ_RX:
            /* Save D1 raw ADC value — hand off to main loop for calculation */
            ms5837_raw_D1 = ((uint32_t)ms5837_rx_buf[0] << 16)
                          | ((uint32_t)ms5837_rx_buf[1] << 8)
                          |  (uint32_t)ms5837_rx_buf[2];
            ms5837_fsm = MS5837_FSM_CALCULATE;
            break;

        default:
            break;
    }
}

void HAL_I2C_ErrorCallback(I2C_HandleTypeDef *hi2c)
{
    if (hi2c->Instance != I2C1) return;
    /* Any I2C error (NACK, BERR, ARLO, TIMEOUT) resets the FSM.
       hi2c->State is already READY when HAL calls this. */
    ms5837_fsm = MS5837_FSM_IDLE;
    ms5837_last_meas = g_ms;  /* back off 1 s before next attempt */
}


/* USER CODE END 0 */
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

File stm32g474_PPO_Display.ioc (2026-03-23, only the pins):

Mcu.UserName=STM32G474CCTx
PA0.GPIO_Label=VIB_PWM
PA0.Signal=S_TIM5_CH1
PA1.GPIO_Label=SENSOR_1
PA1.Signal=OPAMP1_VINP
PA10.GPIO_Label=TFT_CS
PA10.Signal=GPIO_Output
PA11.GPIO_Label=TFT_DC
PA11.Signal=GPIO_Output
PA12.GPIO_Label=TFT_RST
PA12.Signal=GPIO_Output
PA13.Signal=SYS_JTMS-SWDIO
PA14.Signal=SYS_JTCK-SWCLK
PA15.Signal=I2C1_SCL
PA2.GPIO_Label=BTN_M
PA2.Signal=GPIO_Input
PA3.GPIO_Label=BTN_S
PA3.Signal=GPIO_Input
PA5.GPIO_Label=FL_SCK
PA5.Signal=SPI1_SCK
PA7.GPIO_Label=SENSOR_2
PA7.Signal=OPAMP2_VINP
PA9.GPIO_Label=TFT_BLK
PA9.Signal=S_TIM2_CH3
PB0.GPIO_Label=SENSOR_3
PB0.Signal=OPAMP3_VINP
PB12.GPIO_Label=SENS_BAT
PB12.Signal=ADC4_IN3
PB13.GPIO_Label=TFT_SCK
PB13.Signal=SPI2_SCK
PB15.GPIO_Label=TFT_MOSI
PB15.Signal=SPI2_MOSI
PB4.GPIO_Label=FL_MISO
PB4.Signal=SPI1_MISO
PB5.GPIO_Label=FL_MOSI
PB5.Signal=SPI1_MOSI
PB6.GPIO_Label=FL_CS
PB6.Signal=GPIO_Output
PB7.Signal=I2C1_SDA

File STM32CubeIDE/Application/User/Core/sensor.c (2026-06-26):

/*
 * sensor.c
 *
 *  Created on: Nov 14, 2025
 *      Author: imele
 *
 * Two-stage digital filter for O2 sensor ADC readings:
 * 1. Hampel filter: Rejects large outliers/spikes using MAD-based threshold
 * 2. EMA filter: Smooths ADC noise (±2-3 counts) while tracking real changes
 *
 * Filter operates on raw ADC counts (0-4095 range).
 * Conversion to voltage happens AFTER filtering in sensor_data_update().
 */
#include "stm32g4xx_ll_adc.h"
#include "stdint.h"
#include "stdbool.h"
#include "sensor.h"
#include "calibration.h"
#include "screen_manager.h"
#include "drift_tracker.h"

/* Two-stage EMA filter for O2 sensor ADC readings
 *
 * ADC DMA callback rates (continuous mode, 16x oversampling):
 *   ADC1: ~9.5 kHz (3 channels: VREFINT, BAT, SENSOR3)
 *   ADC2: ~14.3 kHz (2 channels: SENSOR1, SENSOR2)
 *
 * Filter response at ~10 kHz effective rate:
 *   S=9   -> α=1/512,  ~54ms time constant (fast response)
 *   Sb=11 -> α=1/2048, ~215ms baseline tracking
 *   K=70  -> ~7ms Hampel window for spike rejection
 *
 * Auto-calibration: 2500 steps ≈ 263ms settling time
 */
#define S   9                     // EMA alpha = 1/512
#define Sb  11                    // Baseline alpha = 1/2048
#define K   70                    // Hampel window: ~7ms at 10kHz
#define SPIKE_K 5                 // MAD multiplier for spike threshold
#define MAD_MIN_COUNTS 2          // Minimum MAD (prevents divide-by-zero)

// Stability-based auto-calibration constants
#define STABLE_THRESHOLD    3     // Max |y - b| difference in ADC counts
#define STABLE_REQUIRED     50    // Consecutive stable samples needed (~5ms)
#define MIN_WARMUP_STEPS    100  // Minimum samples before checking stability
#define MAX_STABILITY_WAIT  0 /* Intentionally 0 — no extra wait beyond MIN_WARMUP_STEPS */

uint16_t steps[SENSOR_COUNT - 2];
static uint16_t stable_count[SENSOR_COUNT - 2];  // Per-sensor stability counter

// In unit test mode, these are defined in mock_sensor_data.c
#ifndef UNIT_TEST
volatile sensor_data_t sensor_data;
uint8_t active_setpoint = 1;  // Default to SP1
#else
extern volatile sensor_data_t sensor_data;
extern uint8_t active_setpoint;
#endif

// Single-stage EMA filter state (filter_step_sensor)
static int32_t lastK[SENSOR_COUNT - 1][K];
static uint8_t k_idx[SENSOR_COUNT - 1];          // ring index per sensor
static int32_t acc_y[SENSOR_COUNT - 1];       // EMA accumulator Q(S) per sensor
static int32_t acc_b[SENSOR_COUNT - 1];         // baseline EMA Q(Sb) per sensor
static bool init_done[SENSOR_COUNT - 1];         // init flag per sensor
static bool startup = true;

static inline int32_t median_int32(const int32_t *a, int n) {
	_Static_assert(K <= 70, "K exceeds median_int32 buffer size (max 70)");

	int32_t t[72] = {0};  // Buffer for sorting (initialized below, works for K up to 70)
	for (int i = 0; i < n; i++)
		t[i] = a[i];  // Copy input array before in-place sort

	for (int i = 1; i < n; i++) {
		int32_t key = t[i];
		int j = i - 1;
		while (j >= 0 && t[j] > key) {
			t[j + 1] = t[j];
			j--;
		}
		t[j + 1] = key;
	}
	return t[n >> 1];
}

static inline int32_t mad_int32_q0(const int32_t *a, int n, int32_t med) {
	_Static_assert(K <= 70, "K exceeds mad_int32_q0 buffer size (max 70)");

	int32_t d[72];
	for (int i = 0; i < n; i++) {
		int32_t diff = a[i] - med;
		d[i] = (diff >= 0) ? diff : -diff;
	}

	for (int i = 1; i < n; i++) {
		int32_t key = d[i];
		int j = i - 1;
		while (j >= 0 && d[j] > key) {
			d[j + 1] = d[j];
			j--;
		}
		d[j + 1] = key;
	}
	return d[n >> 1];
}

int32_t filter_step_sensor(sensor_id_t id, int32_t raw) {
	// Safety: Only filter O2 sensors (SENSOR1-SENSOR3), reject BAT/REFERENCE
	// Filter arrays sized [SENSOR_COUNT-1] = [4], valid indices 0-3
	// But only SENSOR1(0), SENSOR2(1), SENSOR3(2) should use filter
	if (id < SENSOR1 || id > SENSOR3) {
		return raw;
	}

	int32_t *lastK_ch = lastK[id];
	uint8_t *k_idx_ch = &k_idx[id];
	int32_t *acc_y_ch = &acc_y[id];
	int32_t *acc_b_ch = &acc_b[id];
	bool *init_ch = &init_done[id];

	// --- 0) First-call init for this sensor ---
	if (!*init_ch) {
		for (int i = 0; i < K; i++)
			lastK_ch[i] = raw;

		*acc_y_ch = raw << S;   // EMA accumulator in Q(S)
		*acc_b_ch = raw << Sb;  // baseline accumulator in Q(Sb)
		*init_ch = true;
	}

	// --- 5a) Hampel-lite on existing window (DISABLED for testing) ---
	// At 1 kHz sampling, K=7 window is too small (7ms) - disabling Hampel for now

	/* ORIGINAL HAMPEL CODE (disabled for testing): */
	int32_t median = median_int32(lastK_ch, K);
	int32_t mad = mad_int32_q0(lastK_ch, K, median);
	if (mad < MAD_MIN_COUNTS)
		mad = MAD_MIN_COUNTS;

	int32_t x_clip = raw;
	if (mad > 0) {
		int32_t thr = mad * SPIKE_K;
		int32_t diff = raw - median;

		if (diff > thr)
			x_clip = median + thr;
		if (diff < -thr)
			x_clip = median - thr;
	}

	// Update ring buffer for this sensor
	lastK_ch[*k_idx_ch] = x_clip;
	*k_idx_ch = (uint8_t) ((*k_idx_ch + 1) % K);

	// --- 5b) Primary EMA (Q(S)) ---
	*acc_y_ch += (((x_clip << S) - *acc_y_ch) >> S);
	int32_t y = *acc_y_ch >> S;    // back to mV

	// --- 5c) Slow baseline (optional) ---
	*acc_b_ch += (((y << Sb) - *acc_b_ch) >> Sb);
	int32_t b = *acc_b_ch >> Sb;

	// TODO: per-sensor baseline if you want:
	// int32_t y_out = y - ((b - g_b0_uV[id]) >> 3);
	(void) b;   // silence unused for now

	return y;  // filtered mV
}

static inline uint32_t adc_to_uV_at_sensor(uint16_t counts, uint32_t vdda_uv,
		int16_t gain) {
	// Safety: Validate gain to prevent division by zero
	if (gain <= 0) {
		return 0;  // Invalid gain = sensor fault
	}

	// Vin_sensor [µV] = (counts × VDDA[µV]) / (4095 × gain)
	// Use 64-bit intermediate to prevent overflow and preserve precision
	return (uint32_t)(((uint64_t)counts * vdda_uv) / ((uint64_t)4095 * gain));
}
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

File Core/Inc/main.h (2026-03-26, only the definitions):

#define VIB_PWM_Pin GPIO_PIN_0
#define VIB_PWM_GPIO_Port GPIOA
#define SENSOR_1_Pin GPIO_PIN_1
#define SENSOR_1_GPIO_Port GPIOA
#define BTN_M_Pin GPIO_PIN_2
#define BTN_M_GPIO_Port GPIOA
#define BTN_S_Pin GPIO_PIN_3
#define BTN_S_GPIO_Port GPIOA
#define FL_SCK_Pin GPIO_PIN_5
#define FL_SCK_GPIO_Port GPIOA
#define SENSOR_2_Pin GPIO_PIN_7
#define SENSOR_2_GPIO_Port GPIOA
#define SENSOR_3_Pin GPIO_PIN_0
#define SENSOR_3_GPIO_Port GPIOB
#define SENS_BAT_Pin GPIO_PIN_12
#define SENS_BAT_GPIO_Port GPIOB
#define TFT_SCK_Pin GPIO_PIN_13
#define TFT_SCK_GPIO_Port GPIOB
#define TFT_MOSI_Pin GPIO_PIN_15
#define TFT_MOSI_GPIO_Port GPIOB
#define TFT_BLK_Pin GPIO_PIN_9
#define TFT_BLK_GPIO_Port GPIOA
#define TFT_CS_Pin GPIO_PIN_10
#define TFT_CS_GPIO_Port GPIOA
#define TFT_DC_Pin GPIO_PIN_11
#define TFT_DC_GPIO_Port GPIOA
#define TFT_RST_Pin GPIO_PIN_12
#define TFT_RST_GPIO_Port GPIOA
#define FL_MISO_Pin GPIO_PIN_4
#define FL_MISO_GPIO_Port GPIOB
#define FL_MOSI_Pin GPIO_PIN_5
#define FL_MOSI_GPIO_Port GPIOB
#define FL_CS_Pin GPIO_PIN_6
#define FL_CS_GPIO_Port GPIOB

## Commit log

2026-03-19 Initial commit: STM32G474 PPO Display firmware
    Application source, CubeMX project, schematics, housing model.
    LVGL v8.3.11 added as git submodule.
    ST HAL/CMSIS drivers excluded (regenerate via STM32CubeMX).
    [housing.FCStd]
2026-03-22 Fix MS5837 FSM stuck in D2/D1_READ_RX: replace _DMA with _IT on I2C RX
    HAL_I2C_Master_Receive_DMA() was used for 3-byte ADC reads but I2C1 has
    no DMA channel configured in CubeMX (hi2c1.hdmarx == NULL). MasterRxCplt
    callback never fired, leaving the FSM permanently stuck in READ_RX states.
    Replaced both calls with HAL_I2C_Master_Receive_IT() which uses the
    existing I2C1_EV_IRQ (priority 1) and fires the same callback on
    completion. Added HAL_OK return check with IDLE fallback on both sites.
    [main.c, stm32g474_PPO_Display.ioc]
2026-03-22 Add vibro motor warning modes and update README
    Implements non-blocking haptic feedback aligned with the existing
    4-level warning system (NONE / DRIFT / NEAR_CRITICAL / CRITICAL):
    - warning.c: vibro state machine driven by 5ms scheduler tick;
    distinct PWM patterns per severity (1/2/3 pulses at 50/75/99% duty);
    vibro_acknowledge() snoozes motor on BTN_M press without changing
    visual warnings; snooze auto-clears on level change
    - warning.h: vibro_tick_5ms(), vibro_acknowledge(), vibro_is_active()
    - screen_main.c: collect highest warning level across all 3 sensors,
    call warning_trigger_vibration() once per 1Hz update
    - screen_manager.c: BTN_M intercept at top of handle_button() —
    s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
    [main.c, main.h, warning.c]
2026-03-23 Fix 13 safety audit findings: fault handling, data races, overflow, dead code
    Safety fixes applied across firmware and supporting infrastructure:
    - stm32g4xx_it.c: fault handlers now call NVIC_SystemReset() instead of looping
    forever; TIM5 PWM zeroed at register level (HAL unsafe in fault context)
    - main.c: ms5837 init failure sets pressure_valid=false; ADC4 VREFINT+BAT reads
    made atomic under __disable_irq(); removed unused globals (something,
    vbias_effective_mv, vbias_counts_for_adc2)
    - pressure_sensor.c: int64_t intermediate prevents overflow at ~30-bar depth limit
    - button.c: button_get_event() read-clear made atomic under __disable_irq()
    - calibration.c: bounds check on SensorID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
    [button.c, main.c]
2026-03-25 Add dive log module with safety fixes
    - Add dive_log.c/h: append-only profile logging to W25Q128 flash
    - Sectors 18-19: metadata ping-pong (power-fail safe, CRC32)
    - Sectors 20-4095: 32-byte entry log (DIVE_START + DIVE_SAMPLE)
    - 1 Hz tick: dive start at 1 m, 3-min surface timeout, samples on
    depth delta >= 0.5 m or PPO delta >= 20 mbar
    - Deferred sector erase: zone-wrap erases fire at surface only
    - Boot recovery: metadata ping-pong + short forward scan
    - Fix 4 MEDIUM safety audit findings in dive_log.c:
    - Deferred erase only clears pending_erase_addr on W25Q128_OK
    - log_id/dive_active gated on entry_write success (not before)
    - int32_t o2_s_ppo clamped to 0 before uint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
    [dive_log.c, main.c]
2026-03-26 Fix shutdown, safety audit findings across sensor/dive_log/main
    Shutdown fixes (main.c, screen_power_off.c, st7789v.h):
    - Uncomment system_shutdown() call in screen_power_off_action()
    - Fix backlight pin: PA2→PA9 (TFT_BLK/TIM2_CH3 on G474)
    - Fix EXTI wake: remove wrong EXTI9_5/PA8, use BTN_M_Pin/EXTI2
    - Add SLPIN+DISPOFF SPI commands before peripheral stop
    - Refresh IWDG immediately before Stop1 for full ~6s window
    - Stop ADC3/ADC4 DMA in shutdown (were left armed)
    - Add ST7789_SLPIN/DISPOFF constants and SendCmd declaration
    sensor.c safety fixes:
    - Atomic sensor snapshot before multi-field reads (H-2)
    - Narrowing cast on battery voltage multiply (H-9/10)
    dive_log.c/h safety fixes:
    - div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
    [dive_log.c, main.c, main.h]
2026-05-16 Update analysis results, housing, and schematics
    - Refresh static analysis pipeline outputs (cppcheck, clang-tidy, flawfinder, lizard)
    - Add pipeline history snapshot from 2026-03-26
    - Update FreeCAD housing file, remove old FCBak
    - Add MS5837 holder schematic; update PPO display schematic to 2026-05-16
    [housing.FCStd]
2026-06-26 Fix pressure depth sign, surface capture, bottom timer reset, battery voltage calibration
    - pressure_sensor: flip delta sign so diving down gives positive depth
    - ms5837/main: scale pressure ×20 (Pa), capture actual surface pressure on first reading
    - dive_log: add dive_log_is_active(); reset bottom timer when dive ends
    - screen_main: fix negative-depth display formatting
    - sensor: add BAT_CAL_NUM/DEN (1068/1000) to correct ~6.8% voltage under-read from resistor tolerance
    [dive_log.c, main.c, ms5837.c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]

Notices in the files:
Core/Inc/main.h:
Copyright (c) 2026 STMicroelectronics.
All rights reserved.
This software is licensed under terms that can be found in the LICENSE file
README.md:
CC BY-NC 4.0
